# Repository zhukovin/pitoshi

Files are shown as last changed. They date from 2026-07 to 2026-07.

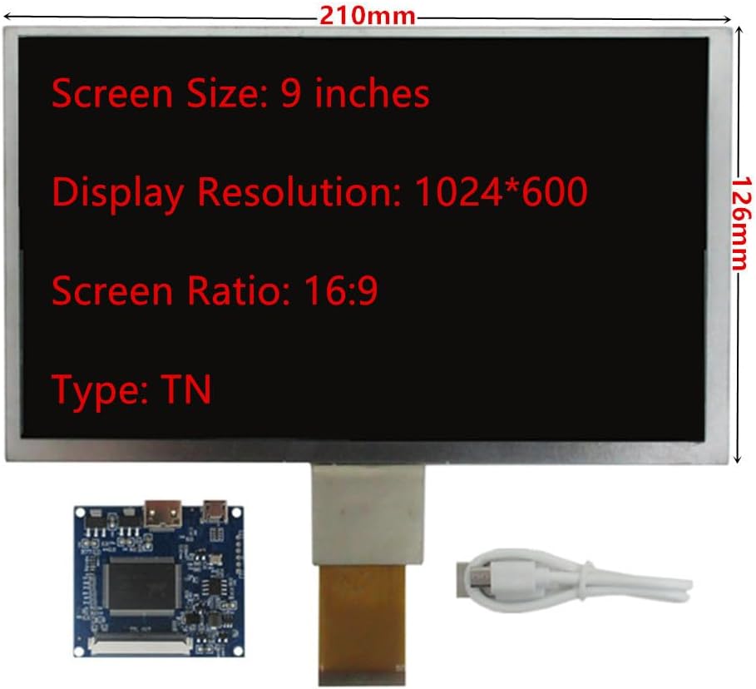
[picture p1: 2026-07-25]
display/docs/51enpO84WiL._AC_SL1000_.jpg

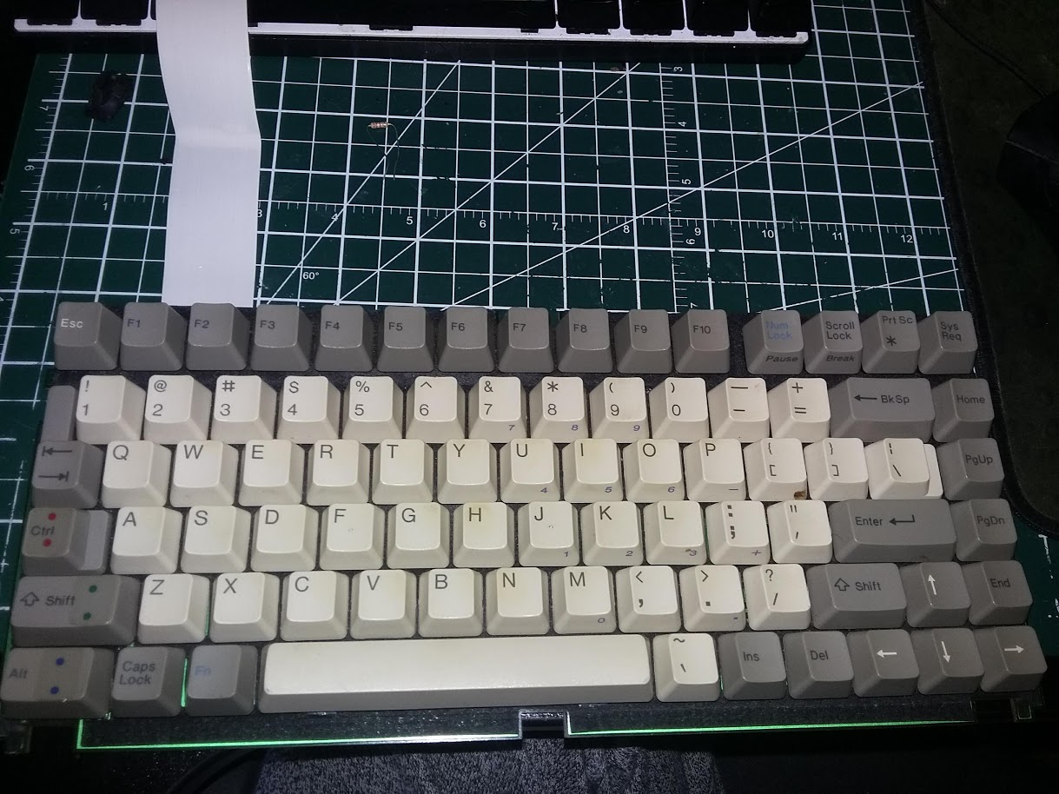
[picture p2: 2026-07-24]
keyboard/docs/misc/xawLbd5.jpeg

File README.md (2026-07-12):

# Toshiba T1200XE Keyboard USB Controller using Raspberry Pi Pico + KMK

## Overview

This project converts the original Toshiba T1200XE laptop keyboard into a modern USB keyboard using a Raspberry Pi Pico (RP2040).

Unlike many modern keyboards, the Toshiba keyboard:

- is a raw keyboard matrix
- has a diode on every key
- uses **active HIGH scanning**
- requires rows to be driven HIGH and columns to use PULL_DOWN inputs

This document describes everything required to reproduce the project from scratch.

---

# Hardware

- Raspberry Pi Pico (RP2040)
- Toshiba T1200XE keyboard
- USB cable
- Soldered connections between keyboard ribbon and Pico GPIO

---

# Software Required

1. CircuitPython
2. CircuitPython Library Bundle
3. adafruit_hid
4. KMK Firmware

---

# IDE Setup (IntelliJ IDEA)

IDEA does not ship with CircuitPython stubs, so `import board`, `import busio`, etc. will show as unresolved by default. Fix:

1. Create a virtual environment in the project root:

```bash
python3 -m venv .venv
source .venv/bin/activate
pip install circuitpython-stubs
```

2. Point IDEA to the venv interpreter:
   `File → Project Structure → Project Settings → Project → SDK → open dropdown → Add Python SDK from disk… → Select existing → Python path → select .venv/bin/python`

3. Invalidate caches to force IDEA to index the new stubs:
   `File → Invalidate Caches → Invalidate and Restart`

After restart, `board`, `busio`, `digitalio`, and other CircuitPython modules will resolve correctly.

> Do not install the PyPI package named `board` — it is unrelated to CircuitPython and will not help.

---

# Installing CircuitPython

Download the latest firmware:

https://circuitpython.org/board/raspberry_pi_pico/

Install:

1. Hold BOOTSEL.
2. Connect Pico to USB.
3. Pico appears as

```
RPI-RP2
```

4. Drag the downloaded `.uf2` file onto the drive.

After reboot it appears as

```
CIRCUITPY
```

---

# Connecting to the Serial Console

The Pico exposes a USB serial (CDC) device once CircuitPython is installed. This is how you see `print()` output, KMK debug logs, and the REPL.

## 1. List available tty devices

**macOS:**

```bash
ls /dev/tty.*
```

The Pico shows up as something like `/dev/tty.usbmodem14101`.

**Linux (including Raspberry Pi):**

```bash
ls /dev/ttyACM*
```

The Pico is usually `/dev/ttyACM0` (or the next free number if other USB-serial devices are already connected).

If several devices are listed and you're not sure which one is the Pico, unplug it, re-run the `ls` command, plug it back in, and re-run again — the device that appears is the Pico. On Linux you can also confirm with:

```bash
ls -la /dev/serial/by-id/
```

which prints a descriptive name (e.g. containing `Raspberry_Pi_Pico` or `CircuitPython`) instead of a generic device number.

## 2. Open the serial console with `screen`

```bash
screen /dev/tty.usbmodem14101 115200
```

(substitute the actual device path from step 1; the baud rate `115200` is conventional and CircuitPython ignores it over USB, but you still need to supply a value).

You should land on a blank terminal connected to the board. If `code.py` is running, any `print()` output or KMK debug lines will stream in as they happen. Press Enter if you see nothing — sometimes the first line is swallowed by `screen` attaching mid-output.

## 3. Useful keys once connected

- **Ctrl+D** — soft-reboot: reloads and re-runs `code.py`.
- **Ctrl+C** — interrupt the running program and drop into the REPL.
- **Ctrl+A** then **K**, then **y** — kill the `screen` session (disconnects so another program, like Mu, can open the port).
- **Ctrl+A** then **D** — detach without killing the session (reattach later with `screen -r`).

Only one program can hold the serial port open at a time — if `screen` won't connect, make sure Mu, `tio`, Arduino IDE's serial monitor, etc. aren't already attached to the same device.

---

# Verify CircuitPython

Create `code.py`

```python
print("Hello CircuitPython")
```

Press Ctrl+D in the serial console.

Expected:

```
Hello CircuitPython
```

---

# Install CircuitPython Libraries

Download:

https://circuitpython.org/libraries

Choose the bundle matching your CircuitPython version.

Extract it.

---

# Install adafruit_hid

Copy

```
lib/adafruit_hid
```

from the bundle into

```
CIRCUITPY/lib/
```

Verify:

```python
from adafruit_hid.keyboard import Keyboard
from adafruit_hid.keycode import Keycode

print("HID installed")
```

---

# Test USB HID

```python
import usb_hid
from adafruit_hid.keyboard import Keyboard
from adafruit_hid.keycode import Keycode

kbd = Keyboard(usb_hid.devices)

kbd.press(Keycode.A)
kbd.release_all()
```

Opening a text editor should automatically type

```
a
```

---

# Install KMK

Download:

https://github.com/KMKfw/kmk_firmware

Copy the folder

```
kmk
```

to

```
CIRCUITPY/
```

Final structure:

```
CIRCUITPY/
│
├── code.py
├── kmk/
└── lib/
    └── adafruit_hid/
```

Verify:

```python
from kmk.keys import KC

print("KMK installed")
```

---

# Toshiba Keyboard Matrix

The Toshiba T1200XE keyboard is

```
8 rows
11 columns
```

Total GPIO required:

```
19
```

---

# GPIO Assignment

Rows

```python
ROWS = [
    board.GP11,
    board.GP12,
    board.GP13,
    board.GP14,
    board.GP20,
    board.GP15,
    board.GP22,
    board.GP21,
]
```

Columns

```python
COLS = [
    board.GP0,
    board.GP1,
    board.GP2,
    board.GP4,
    board.GP3,
    board.GP6,
    board.GP5,
    board.GP7,
    board.GP8,
    board.GP9,
    board.GP10,
]
```

---

# Matrix Polarity

Initially the keyboard was assumed to use the common polarity:

```
Rows LOW
Columns PULL_UP
```

Nothing worked.

Testing revealed that Toshiba uses the opposite polarity.

Correct scan:

```
Rows OUTPUT

inactive = LOW
active = HIGH

Columns INPUT

PULL_DOWN

Pressed key = HIGH
```

This was verified experimentally.

---

# Matrix Scanner

The discovery scanner works like:

```
For every row

    set every row LOW

    drive current row HIGH

    read every column

    if HIGH

        key pressed
```

This scanner was used to build the entire keyboard matrix.

---

# Key Matrix

(The completed matrix mapping goes here.)

Example:

| Row  | Col  | Key  |
|---|---|---|
| 0 | 0 | F1 |
| 0 | 1 | F2 |
| 0 | 2 | Esc  |
| ...  | ...  | ...  |

---

# KMK Configuration

Example:

```python
import board

from kmk.kmk_keyboard import KMKKeyboard
from kmk.keys import KC
from kmk.scanners import DiodeOrientation

keyboard = KMKKeyboard()

keyboard.row_pins = (
    board.GP11,
    board.GP12,
    board.GP13,
    board.GP14,
    board.GP20,
    board.GP15,
    board.GP22,
    board.GP21,
)

keyboard.col_pins = (
    board.GP0,
    board.GP1,
    board.GP2,
    board.GP4,
    board.GP3,
    board.GP6,
    board.GP5,
    board.GP7,
    board.GP8,
    board.GP9,
    board.GP10,
)

keyboard.diode_orientation = DiodeOrientation.ROW2COL
```

---

# Debounce

Initially

- Enter occasionally generated two presses.
- Shift sometimes failed.

Adding debounce solved the problem.

Example:

```python
from kmk.modules.debounce import Debounce

keyboard.modules.append(Debounce())
```

---

# Disable KMK Debug

If KMK prints

```
kmk.keyboard:
```

messages continuously

disable debugging:

```python
import kmk

kmk.debug_enabled = False
```

---

# Disable CircuitPython REPL

Create `boot.py`

```python
import usb_cdc

usb_cdc.enable(console=False, data=True)
```

This removes the REPL console while keeping a serial data port.

---

# Disable USB MIDI (Pico Shows Up as a Sound Card)

CircuitPython enables a USB MIDI interface by default. USB MIDI streaming
is technically a subclass of the USB *Audio* class, so on Linux hosts it
shows up as an extra ALSA sound card (`cat /proc/asound/cards` lists it as
`Pico [USB-Audio]`) even though KMK never uses it and no real audio is
involved. Harmless, but confusing when diagnosing audio setups.

Create `boot.py`

```python
import usb_midi

usb_midi.disable()
```

`boot.py` only runs on a full boot, not on the auto-reload triggered by
saving `code.py` — unplug and replug the Pico (or press its reset button)
for this to take effect.

---

# Testing

Test in this order:

- letters
- numbers
- arrows
- Shift
- Ctrl
- Alt
- Enter
- Backspace

---

# Future Improvements

## Fn Key

Implement Toshiba Fn layer using KMK Layers module.

Possible functions:

- brightness
- volume
- overlay keypad
- function remapping

---

## Media Keys

KMK supports:

- Volume Up
- Volume Down
- Mute
- Play
- Pause

---

## Multiple Layers

Possible layers:

Layer 0

Original Toshiba layout

Layer 1

Fn layer

Layer 2

Gaming

Layer 3

Mac layout

---

# Lessons Learned

The most important discovery during reverse engineering was that the Toshiba keyboard **does not use the common active-low scan method**.

Correct operation requires:

```
Rows:
    OUTPUT
    inactive LOW
    active HIGH

Columns:
    INPUT
    PULL_DOWN

Pressed key:
    HIGH
```

This single discovery made the keyboard immediately functional.

---

# Useful Links

CircuitPython

https://circuitpython.org/

CircuitPython Libraries

https://circuitpython.org/libraries

KMK

https://github.com/KMKfw/kmk_firmware

KMK Documentation

https://kmkfw.io

Raspberry Pi Pico

https://www.raspberrypi.com/products/raspberry-pi-pico/

---

Project status:

✅ CircuitPython installed

✅ USB HID working

✅ Keyboard matrix reverse engineered

✅ Active-HIGH polarity discovered

✅ GPIO mapping complete

✅ Key matrix mapped

✅ KMK running

✅ Toshiba keyboard fully functional over USB

## Manually Creating a Wi-Fi Connection with NetworkManager

If the Raspberry Pi detects nearby Wi-Fi networks (`iwlist wlan0 scan` works) but does not have any saved Wi-Fi connections (`nmcli connection show` only lists `lo` and `Wired connection 1`), you can manually create a connection profile.

### 1. Create a new Wi-Fi connection

```bash
sudo nmcli connection add \
    type wifi \
    ifname wlan0 \
    con-name home \
    ssid "az"
```

This creates a new connection profile named **home** for the Wi-Fi network with SSID **az**.

### 2. Configure the security type

```bash
sudo nmcli connection modify home \
    wifi-sec.key-mgmt wpa-psk
```

This tells NetworkManager that the network uses WPA/WPA2 Personal authentication.

### 3. Set the Wi-Fi password

```bash
sudo nmcli connection modify home \
    wifi-sec.psk "12345678"
```

### 4. Activate the connection

```bash
sudo nmcli connection up home
```

If successful, the Raspberry Pi will obtain an IP address from the router.

### 5. Verify the connection

Check the assigned IP address:

```bash
ip addr show wlan0
```

Test Internet connectivity:

```bash
ping -c 4 8.8.8.8
```

Test DNS resolution:

```bash
ping -c 4 google.com
```

### Useful NetworkManager commands

List all saved connections:

```bash
nmcli connection show
```

List network devices:

```bash
nmcli device
```

Show detailed information about the Wi-Fi interface:

```bash
nmcli device show wlan0
```

List nearby Wi-Fi networks:

```bash
nmcli device wifi list
```

Force a Wi-Fi rescan:

```bash
nmcli device wifi rescan
```

Bring the connection up again later:

```bash
sudo nmcli connection up home
```

Disconnect from Wi-Fi:

```bash
sudo nmcli connection down home
```

Delete the connection profile:

```bash
sudo nmcli connection delete home
```

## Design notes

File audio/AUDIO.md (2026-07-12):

# Audio Setup — PAM8406 Amp via the 3.5mm Jack

Hardware: Raspberry Pi 3 Model B (Rev 1.2), a PAM8406 class-D amp board, two
speakers, connected through the Pi's built-in 3.5mm AV jack. Display is
HDMI-only (no speakers), so the analog jack is the only audio output that
matters here.

## TL;DR — The Fix

The Pi has **two separate ALSA sound cards** and it's easy to test the wrong
one:

```
card 0: vc4hdmi     [vc4-hdmi]           — HDMI audio (no speakers on this display)
card 1: Headphones  [bcm2835 Headphones] — the analog 3.5mm jack you actually want
card 2: Pico        [USB-Audio]          — the keyboard project's own Pico, enumerates as a sound card
```

Find your own card numbers (they can differ by OS image/revision):

```
aplay -l
cat /proc/asound/cards
```

Test the *analog* card directly, bypassing PipeWire, to confirm the hardware
path works at all:

```
speaker-test -D plughw:1,0 -c2 -twav -l1
```

Make sure PipeWire's default output sink is the analog device, not HDMI:

```
wpctl status                 # look under Audio → Sinks for the "*" (default) marker
wpctl set-default <id>       # id of "Built-in Audio Stereo" (NOT the one labeled "(HDMI)")
wpctl set-mute <id> 0
wpctl set-volume <id> 100%
```

Confirm PipeWire itself can play sound through it:

```
pw-play /usr/share/sounds/alsa/Front_Center.wav
```

**Persist across reboot** — two layers need saving, PipeWire's default-sink
preference and the raw ALSA hardware mixer level:

```
wpctl set-default <id>              # WirePlumber remembers this by device name, survives reboot
amixer -c 1 sset PCM 100% unmute    # raw hardware gain — resets on reboot unless saved
sudo alsactl store 1                # writes card 1's mixer state to /var/lib/alsa/asound.state,
                                     # reloaded automatically at boot by the alsa-restore service
```

Verify with a reboot:

```
sudo reboot
# after it comes back:
wpctl status
speaker-test -D plughw:1,0 -c2 -twav -l1
```

`wpctl status` will show a new numeric sink id (ids are reassigned every
boot) but the same device should still be marked default `*`, and
`Settings → Default Configured Devices` should list something like
`alsa_output.platform-3f00b840.mailbox.stereo-fallback` — that's the
persisted preference, keyed by device name rather than the id.

### Two things that look like bugs but aren't

- **50Hz hum when you touch the bare jack, before anything is really
  playing.** Normal. A high-impedance analog audio line picks up ambient
  mains hum capacitively through your body when touched. It doesn't indicate
  a fault. If the hum persists *during actual playback*, that's a different
  problem — almost always a ground loop between the Pi's power supply and
  the amp's power supply if they're on separate wall adapters. Fix by
  sharing a common ground (power the PAM8406 from the Pi's own 5V rail, or
  put both PSUs on the same power strip) or adding an inline ground-loop
  isolator.
- **`amixer` reports `Playback channels: Mono` for card 1's `PCM` control.**
  That's describing the *mixer control*, not the audio stream. Capabilities
  `pvolume-joined pswitch-joined` mean the Pi's onboard PWM-based DAC only
  exposes one shared volume/mute register for both channels — there's no
  independent L/R gain in hardware. The actual PCM path is genuine 2-channel
  stereo, confirmed by `speaker-test -c2` announcing distinct "Front Left" /
  "Front Right" and both speakers working independently through the
  PAM8406.
- **Card 2, `Pico [USB-Audio]`, isn't a real audio device either.** It's
  the keyboard project's own Raspberry Pi Pico. CircuitPython enables a USB
  MIDI interface by default, and USB MIDI streaming is technically a
  subclass of the USB *Audio* class, so Linux's `snd-usb-audio` driver
  picks it up as a sound card even though no real audio is involved. It's
  not the cause of any audio bug here, but it's worth silencing so it can't
  confuse future diagnostics (or ever become a stray default sink via
  WirePlumber's hotplug auto-switching, see step 7). Create `boot.py`
  alongside `code.py` on the `CIRCUITPY` drive:

  ```python
  import usb_midi

  usb_midi.disable()
  ```

  `boot.py` only runs on a full boot, not on the auto-reload triggered by
  saving `code.py` — unplug and replug the Pico (or press its reset button)
  for this to take effect. See the main `README.md`'s "Disable USB MIDI"
  section.

---

## Diagnostic Journey — How We Got Here

### 1. The symptom

No sound at all through the PAM8406 + speakers when connected via the
3.5mm jack. Touching the bare jack produced a 50Hz hiss on both channels.
Working theory going in: the Pi is routing audio to HDMI, and the HDMI
display has no speakers to reveal that.

### 2. Identify the audio stack

```
pactl --version 2>/dev/null && echo "PulseAudio"
wpctl status 2>/dev/null && echo "PipeWire"
```

Result: PipeWire 1.4.2 (Raspberry Pi OS Bookworm default), not PulseAudio.
This determined which command family to use for the rest of the
investigation (`wpctl`/`pw-*` instead of `pactl`).

### 3. First look at `wpctl status`

```
wpctl status
```

Showed two sinks:

```
35. Built-in Audio Digital Stereo (HDMI) [vol: 0.40]
58. Built-in Audio Stereo               [vol: 1.00]   ← marked default (*)
```

This complicated the initial "it's routed to HDMI" theory — PipeWire
already believed the analog sink was default, at full volume, unmuted.
Something below the PipeWire layer had to be the culprit.

### 4. Rule out a muted/zero PipeWire sink and a jack-less Pi 5

```
wpctl get-volume 58        # → Volume: 1.00, not [MUTED]
cat /proc/device-tree/model # → Raspberry Pi 3 Model B Rev 1.2
```

The volume readout confirmed the sink wasn't secretly muted at the
PipeWire layer. The model check ruled out a real gotcha: the Raspberry Pi 5
removed the analog 3.5mm audio jack entirely, so a "healthy-looking" ALSA
node can exist in software with no physical jack behind it. Not the case
here — a Pi 3B genuinely has the jack.

### 5. Drop to the raw ALSA mixer

```
amixer -c 0 controls
```

```
numid=1,iface=CARD,name='HDMI Jack'
numid=6,iface=MIXER,name='PCM Playback Volume'
numid=5,iface=PCM,name='ELD'
numid=4,iface=PCM,name='IEC958 Playback Default'
numid=3,iface=PCM,name='IEC958 Playback Mask'
numid=2,iface=PCM,name='Playback Channel Map'
```

The controls on card 0 are all HDMI-specific (`HDMI Jack`, `ELD`,
`IEC958`/S/PDIF). **Card 0 is the HDMI audio card, not the analog jack.**
Any test run against `hw:0` or `plughw:0,0` was silently testing the wrong
device the entire time.

### 6. Confirm the wrong-card theory

```
speaker-test -D plughw:0,0 -c2 -twav -l1
```

Silent, as expected — this was playing to the HDMI card, and the monitor
has no speakers.

### 7. Enumerate the real cards

```
aplay -l
cat /proc/asound/cards
```

```
card 0: vc4hdmi        - vc4-hdmi
card 1: Headphones     - bcm2835 Headphones     ← the real analog jack
card 2: Pico           - USB-Audio, Raspberry Pi Pico
```

Card 1 is the actual analog output. Card 2 was an unexpected find: the
Toshiba keyboard's own Pico microcontroller enumerates as a USB audio
device on this machine, purely incidental to this repo's KMK firmware
project. Not the cause of the silence, but flagged as a future gotcha —
WirePlumber tends to auto-switch its default sink to the most recently
connected audio device, so unplugging/replugging the keyboard could
someday flip default output away from the speakers.

### 8. Test the correct card

```
speaker-test -D plughw:1,0 -c2 -twav -l1   # ALSA-direct, bypassing PipeWire — worked
pw-play /usr/share/sounds/alsa/Front_Center.wav  # through PipeWire's existing default sink — also worked
```

Both worked. Conclusion: there never was a real routing bug — PipeWire had
the correct analog sink set as default from the start. Every earlier
"no sound" result was from pointing test commands (`plughw:0,0`) at the
HDMI card by mistake.

### 9. Make it durable

Since the working state was arrived at manually mid-session, the last step
was ensuring it survives a reboot rather than reverting to whatever
PipeWire/ALSA pick by default:

```
wpctl set-default 58
wpctl set-mute 58 0
wpctl set-volume 58 100%
amixer -c 1 sset PCM 100% unmute
sudo alsactl store 1
sudo reboot
```

### 10. Verify persistence

Post-reboot:

```
wpctl status
```

```
45. Built-in Audio Digital Stereo (HDMI) [vol: 0.40]
55. Built-in Audio Stereo               [vol: 1.00]   ← still marked default (*)
...
Settings
 └─ Default Configured Devices:
         0. Audio/Sink alsa_output.platform-3f00b840.mailbox.stereo-fallback
```

The sink's numeric id changed (58 → 55, ids are reassigned every boot) but
it's still the default, at full volume, and the `Default Configured
Devices` entry shows WirePlumber persisted the choice by device name —
exactly what `wpctl set-default` is supposed to produce.

### 11. One last loose end: "why does it say Mono?"

```
amixer -c 1 sset PCM 100% unmute
```

```
Simple mixer control 'PCM',0
  Capabilities: pvolume pvolume-joined pswitch-joined
  Playback channels: Mono
  Limits: Playback -10239 - 400
  Mono: Playback 400 [100%] [4.00dB] [on]
```

`pvolume-joined pswitch-joined` means the volume and mute switch are a
single control shared by both channels — the Pi's onboard PWM-based analog
DAC just doesn't expose independent per-channel gain in hardware. That's
why the *simple mixer control* is labeled "Mono." The PCM audio stream
itself is real 2-channel stereo, as already proven in step 8 by
`speaker-test -c2` announcing distinct Front Left / Front Right channels
and both speakers working correctly off the PAM8406.

### 12. Silencing the phantom sound card

Card 2 (`Pico [USB-Audio]`, spotted in step 7) turned out to be the
keyboard's own microcontroller, not anything audio-related — CircuitPython
enables a USB MIDI interface by default, and MIDI streaming is a subclass
of the USB Audio class, so `snd-usb-audio` claims it. It never caused this
particular bug, but left alone it's a standing risk for WirePlumber to
someday auto-switch default output to it on hotplug. Fixed at the source,
in the keyboard firmware repo, with `boot.py`:

```python
import usb_midi

usb_midi.disable()
```

After unplugging/replugging the Pico, `cat /proc/asound/cards` no longer
lists it.

## Cast of Commands

| Command | What it told us |
|---|---|
| `pactl --version` / `wpctl status` | Which audio server is running (PipeWire, not Pulse) |
| `wpctl status` | Sink list, which one is default, software volume |
| `wpctl get-volume <id>` | Whether a sink is muted at the PipeWire layer |
| `cat /proc/device-tree/model` | Confirms the board actually has a physical 3.5mm jack (Pi 5 doesn't) |
| `amixer -c <N> controls` / `scontrols` | Raw ALSA mixer controls for a card — reveals what the card actually *is* (HDMI vs analog) |
| `aplay -l` / `cat /proc/asound/cards` | Ground-truth list of ALSA card indices and names |
| `speaker-test -D plughw:<N>,0 -c2 -twav -l1` | ALSA-direct playback test, bypassing PipeWire entirely |
| `pw-play <file>` | Playback test through PipeWire's current default sink |
| `wpctl set-default <id>` / `set-mute` / `set-volume` | Pin PipeWire's default sink, persisted by device name |
| `amixer -c <N> sset PCM 100% unmute` + `sudo alsactl store <N>` | Save the raw ALSA hardware mixer level so it survives reboot |
| `boot.py` with `usb_midi.disable()` (on the Pico) | Stops the keyboard's Pico from enumerating as a phantom `USB-Audio` sound card |

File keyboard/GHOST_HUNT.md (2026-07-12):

# The Ghost Hunt

### How a 1987 Toshiba keyboard, a Raspberry Pi Pico, and a service manual PDF conspired to teach me more about connector corrosion than I ever wanted to know.

---

## Prologue

This repo exists because a Toshiba T1200XE keyboard — the real deal, raw matrix, active-high rows, diode on every key — got a second life behind a Raspberry Pi Pico running [KMK](https://github.com/KMKfw/kmk_firmware). CircuitPython installed, matrix reverse-engineered, polarity quirks discovered the hard way (see the README's "Lessons Learned" — rows HIGH, columns pulled down, opposite of what every tutorial assumes). By the time the Fn layer and NumLock overlay were working, it felt done.

It was not done.

## Chapter 1 — Six Keys That Wouldn't Behave

The symptom showed up as double-vision on the function-key strip. Run `xev`, press a key, watch what comes out:

```
F3        -> F3, Next (PgDn)
F5        -> F5, F7
F7        -> F7, F9
F8        -> F8, F10
F9        -> F9, End
Next(PgDn)-> Next, F5
```

Six keys, all misbehaving, all producing exactly *one* extra keystroke each. And, separately, a seventh mystery: PrtSc produced nothing at all — not even a hint of activity.

The obvious question, and the one this whole hunt was really about: **is this hardware or software?** A 39-year-old keyboard and a freshly-written matrix scanner are both perfectly capable of being the culprit, and nothing about "I press one key, two happen" tells you which.

## Chapter 2 — Teaching the Firmware to Confess

The keymap looked clean — every matrix position mapped to exactly one key, no obvious dual-binding bug. But "the code looks right" isn't evidence. What was needed was a window into what the *matrix scanner itself* was seeing, before KMK's key-processing had a chance to touch it.

KMK already had the hook for this — one flag flip:

```python
Debug(__name__).enabled = True
```

...and a serial console (`screen /dev/tty.usbmodemXXXX 115200`) turned the Pico into a live logger of every raw scan event. Press F3, and instead of guessing, you'd *see* this:

```
395179 kmk.keyboard: <Event: key_number 22 pressed>: KeyboardKey(code=60)
395221 kmk.keyboard: <Event: key_number 33 pressed>: KeyboardKey(code=78)
395297 kmk.keyboard: <Event: key_number 22 released>: KeyboardKey(code=60)
395308 kmk.keyboard: <Event: key_number 33 released>: KeyboardKey(code=78)
```

Two genuinely distinct matrix positions (`22` and `33`) firing from one physical keypress. Case closed on "is this a firmware keymap bug" — it flatly wasn't. The ghost was happening at the electrical level, before software ever got a vote. **Hardware, confirmed.**

But *what kind* of hardware fault was still wide open.

## Chapter 3 — Finding the Shape of the Problem

With `key_number = row × 11 + col` in hand, the six broken pairs turned into coordinates, and the coordinates turned into a pattern: every ghost was the **same column, the next row in scan order** — a chain running row 2 through row 7. Rows 0 and 1 (F1/F2, F11/F12) sat outside it entirely.

That looked like a smoking gun for a scanning-timing artifact — until a control test broke the theory cleanly. TAB lives at row 2, column 2, right next to F3's row 2, column 0. If the *row* itself were compromised, TAB should ghost into Q below it exactly like F3 ghosts into PgDn.

TAB was rock solid. Every single time.

So the fault wasn't "row 2's wire is bad" — it was specific to *columns 0 and 1*, the narrow two-column strip where all the F-keys live. Theory revised: something localized to that F-key strip, not the row conductors generally.

Then a second axis showed up, unannounced. Pressing F12 occasionally produced F12 *and* F11 — a same-row, neighboring-*column* ghost, the mirror image of the row-axis chain:

```
!! GHOST: F12 press also saw F11, ~40ms later, intermittent (~29% of presses)
```

And then F4 → F3, which turned out to be the most reliable ghost of the entire investigation — **100% reproducible**, a tight and consistent ~15ms lag every single time, versus the 12-70ms jittery lag everywhere else. Not all ghosts were equal; some pairs had a much more "established" fault than others.

By now there were two independent axes of crosstalk (row-adjacent *and* column-adjacent), variable intermittency per pair, and a working hypothesis: **general degradation across the whole F-key strip**, not one single crack in one single spot.

## Chapter 4 — Ruling Out the Diode

A keyboard where "every key has a diode" invites an obvious question: is a bad diode doing this? The answer turned out to be no, and *why not* is worth remembering: a per-key diode sits in series with its own switch. A shorted F3 diode wouldn't make col0 spike only when F4 is pressed — it would make F3 fire on *every single scan* of its row, constantly, since diode current doesn't care whether F4 is pressed at all. That's not what was happening. The real requirement was a path that bypassed the switches and diodes entirely — a bridge directly between two column (or row) *traces*.

And the fact that the ghosting only ever ran one direction (F4→F3, never F3→F4) pointed at something specific: not a clean resistive short, but something with a built-in asymmetry — corrosion between two copper surfaces can behave like an accidental rectifying junction (the "rusty bolt effect"), conducting one way far better than the other. Nobody needed to open the keyboard to guess this; it was a prediction the evidence made *before* the connector was ever inspected.

## Chapter 5 — Building Instruments

Eyeballing debug logs one keypress at a time doesn't scale to "let's get a statistically convincing number of samples." So the toolbox grew:

- **`diagnostics/ghost_key_test.py`** — talks straight to `keypad.KeyMatrix`, bypassing KMK and the OS entirely. Walks a target key, counts clean presses, and the instant a ghost shows up mid-press it prints exactly what leaked in and moves on. First real-world run: pointed at F7, ghost caught on **press #1**.
- **`diagnostics/pattern_anomaly_test.py`** — the free-form version. No fixed target, no script to follow — just mash the keyboard naturally, and it watches for any key showing up while another is still held (which should never happen if you're only pressing one key at a time). Catches anomalies anywhere on the board, not just the already-known F-key suspects, and prints them as a compact pattern:

  ```
  !! I saw this pattern "aaabaaa" - is that intended?
     a=F7, b=F9
  ```

  with a live single-line counter (`F7 x7`) that keeps ticking through the noise, only breaking to a new line when you genuinely switch keys.

The full-strip walk of `ghost_key_test.py` actually produced a false-negative-*looking* result once — F7 tested clean after a 500-press slog through F1 through F6 first. Not a bug: it just never got a fair shot at F7 before patience ran out. Lesson learned and folded back into the tool: an `ONLY_TEST = ['F7']` override to jump straight to the key in question, which is exactly what caught the ghost on the very next attempt.

## Chapter 6 — The PCB, the Tape, and an Alibi

A scan of the keyboard PCB's solder side came next — dense fields of solder joints, scattered black axial diodes, and a Sumitomo FFC ribbon exiting toward what used to be the system board. Two blue tape flags marked, by hand, the physical locations the multimeter should care about: F7 and F9.

Zooming into those tape marks (a few rounds of `sips --cropOffset` standing in for a proper macro lens) revealed tiny silkscreened reference numbers: **118** and **120**. And sitting silently *between* them, unmarked: **119** — almost certainly F8.

That was a small, sharp piece of evidence. If the fault were simple physical adjacency — two neighboring pads on the board touching — F8 should be the first casualty, sitting as it does directly between F7 and F9. It wasn't (on that axis, anyway — more on that in a moment). Whatever was bridging row 5 and row 6 wasn't happening at the keyswitch pads at all. It was happening somewhere else entirely.

## Chapter 7 — The Rosetta Stone

The somewhere else turned out to be hiding in plain sight, in a page from Toshiba's own service manual: **Table B-14, Keyboard I/F connector pin assignment**. Eleven `KBOT` column-strobe lines, eight `KBRT` row-return lines, each with its own connector pin number.

Lining that table up against `code.py`'s oddly-jumbled `row_pins` tuple (`GP11, GP12, GP13, GP14, GP20, GP15, GP22, GP21` — which never made much sense as a deliberate GPIO choice) suddenly explained everything: it wasn't random at all. It was simply the connector's pins, 14 through 22, wired in physical order to whatever Pico pin was next in reach. Once that clicked, every single ghost pair could be translated into **connector pin numbers**:

| Ghost pair | Connector pins | Adjacent? |
|---|---|---|
| F3 → PgDn | 16 ↔ 17 | yes |
| F5 → F7 | 19 ↔ 20 | yes |
| **F7 → F9** | **20 ↔ 21** | **yes** |
| F9 → End | 21 ↔ 22 | yes |
| F4 → F3 | 2 ↔ 1 | yes |
| F12 → F11 | 2 ↔ 1 | yes (same pins) |
| PgDn → F5 | 17 ↔ 19 | one pin gap (GND) |

Six of seven ghosts, every single one, mapped onto **physically adjacent pins on the keyboard's own connector**. Not the PCB matrix. Not the keyswitches. The connector itself — most likely corrosion or contamination bridging neighboring contacts on a decades-old ribbon interface. It also closed the loop on F8's alibi from Chapter 6: F8 was never innocent, it just ghosts through *its own* row-mate pin (into F10, right there in the original six symptoms from Chapter 1) rather than through its physical neighbor on the PCB. Once you're looking at the connector instead of the board, F8's behavior stops being a mystery and becomes confirmation.

## Chapter 8 — Chasing a Ghost That Wouldn't Sit Still

Armed with exact pin numbers, a multimeter in diode-test mode should have been able to close this out. It didn't — every reading at rest came back `1.` (open), on every polarity, on every pin pair. That wasn't a dead end, though; it was consistent with everything already known. The ghost was never a hard, permanent short — it fired on roughly 40-100% of presses depending on the pair, with 10-70ms of jitter and inconsistent release ordering. A DMM sampling a couple of times a second was never going to catch something that transient.

That pushed the investigation toward an oscilloscope setup — trigger on the legitimate keypress, watch the *victim* column line (not the actively-driven row line, which a healthy push-pull output would just stomp flat regardless of a marginal leak) for an unexplained pulse riding in on the neighboring row's timeslot. Persistence mode, mash the key a few dozen times, let the rare ~40% events paint themselves onto the screen as a visibly distinct trace. The plan was solid. It never had to be executed.

## Chapter 9 — The Software Band-Aid

While the physical fix was still an open question, there was no reason to keep living with doubled keystrokes. Since every ghost pair was now precisely characterized — which key triggers which, and roughly how long the lag runs — the fix could be pushed into firmware as a stopgap: **`ghost_filter.py`**, a thin wrapper around `MatrixScanner` that watches raw `key_number` events, and if a known ghost key's press shows up within 200ms of its trigger while the trigger is still held, eats both the press and its matching release before KMK's core ever sees them.

```python
GHOST_MAP = {
    22: {33},  # F3 -> PgDn/Next
    33: {44},  # PgDn/Next -> F5
    44: {55},  # F5 -> F7
    55: {66},  # F7 -> F9
    66: {77},  # F9 -> End
    56: {67},  # F8 -> F10
    12: {11},  # F12 -> F11
    23: {22},  # F4 -> F3
}
```

Deliberately a mitigation, not a cure — it masks the symptom at the cost of a small risk (fine here, since none of these pairs are ever used back-to-back on purpose) and does nothing if the underlying fault ever gets worse. But it meant the keyboard was fully usable while the actual hardware investigation kept going in the background.

## Chapter 10 — The Cure

In the end, the fix was almost anticlimactic compared to the investigation: **isopropyl alcohol**, applied to the connector contacts the service-manual table had pointed to, cleaned away whatever film — corrosion, oxidation, decades of dust — had been marginally bridging those neighboring pins. Ghosting: gone.

It's a satisfying ending precisely *because* it matches the theory built chapter by chapter: an intermittent, force-dependent, one-directional, connector-localized fault is exactly what a thin layer of contamination between two adjacent contacts looks like — and exactly what a swab of IPA fixes.

## Epilogue — The One That Got Away

PrtSc never got its resolution, and it's worth recording *why* it was set aside rather than pretending it was solved. The debug log settled the hardware question decisively:

```
721131 kmk.keyboard: <Event: key_number 75 pressed>: KeyboardKey(code=70)
```

Code 70 is the correct, standard HID usage for Print Screen. The switch, the matrix, and KMK all do their job perfectly. Whatever swallows PrtSc before it reaches `xev` lives downstream — almost certainly a desktop environment or screenshot utility holding a global grab on that key, a very ordinary X11 behavior that has nothing to do with a 1987 keyboard at all. Good to know, not worth chasing further.

## Cast of Tools

| Tool | Role |
|---|---|
| `xev` | Where the mystery started — first sighting of doubled keys |
| KMK `Debug` flag + serial console | Turned the firmware into an eyewitness |
| `diagnostics/ghost_key_test.py` | Scripted, repeatable per-key ghost testing |
| `diagnostics/pattern_anomaly_test.py` | Free-form, whole-keyboard anomaly watch |
| Multimeter (continuity + diode-test mode) | Ruled permanent shorts in and out |
| PCB photos + `sips` crops | Read the board's own silkscreen for ground truth |
| Toshiba service manual, Table B-14 | The Rosetta Stone — pin numbers that cracked the whole case |
| `ghost_filter.py` | The stopgap that kept the keyboard usable mid-investigation |
| Isopropyl alcohol | The actual cure |

## Lessons for Fellow Ghost Hunters

1. **Push the observation point as close to the hardware as you can.** `xev` told us *that* something was wrong; KMK's raw `key_number` log told us *where*, at the electrical level, before any software could be blamed or exonerated.
2. **Let control tests kill your theories.** TAB not ghosting is what actually saved this investigation from stalling on a wrong hypothesis about row conductors.
3. **A photo with a ruler (or in this case, a service manual with pin numbers) beats a guess every time.** The connector table did more in one afternoon than every prior physical inspection combined.
4. **Intermittent and directional is a different animal from "shorted."** Timing jitter and one-way conduction are themselves evidence — they pointed at corrosion long before any cleaning happened.
5. **A software mitigation is not admitting defeat.** Shipping `ghost_filter.py` bought a fully usable keyboard while the real fix was still being hunted down — and it's still sitting there, harmless, now that it has nothing left to catch.

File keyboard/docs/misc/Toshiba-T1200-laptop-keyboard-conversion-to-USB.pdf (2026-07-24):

Toshiba T1200 laptop keyboard conversion to USB.

The key matrix (https://imgur.com/a/L19OMkR) was determined by devicemodder2 and described in a Reddit post (https://www.reddit.com/r/olkb/comments/dk514w/using_existing_laptop_keyboard_from_toshiba_t1200/) as an 11*8 matrix with 11 columns and 8 rows as pictured here. (https://imgur.com/a/yo9EHeh)

The Teensy LC circuit board is designed for an Aliexpress 22 pin 1.25mm pitch connector (https://www.aliexpress.com/item/33053230433.html?spm=2114.12010615.8148356.6.631943d6O5EdmI) with thru-hole pins. The board will also work with a Molex connector (https://www.molex.com/pdm_docs/sd/520452245_sd.pdf) (last time buy) and a TE connector (https://www.te.com/commerce/DocumentDelivery/DDEController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) available from Digikey.

The T1200 connector board has the same Teensy I/O to FPC pin translation table as the standard Teensy LC board seen in my Instructable.

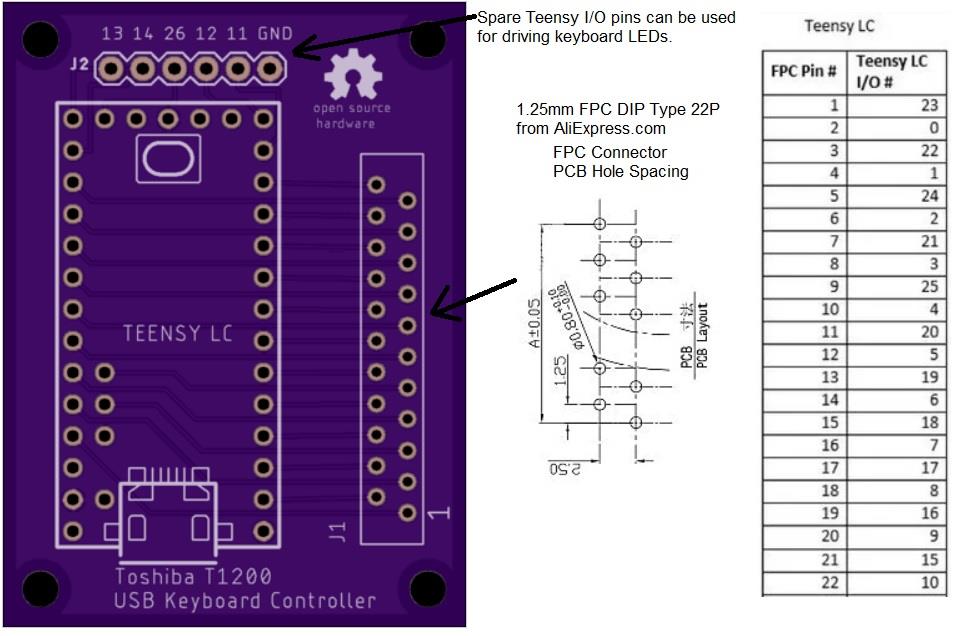
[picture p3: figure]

The Eagle board file “T1200.brd” can be fabricated directly by OSH Park. The zipped Gerber file “T1200_2020-04-27.zip” is formatted for fabrication by JLCPCB.

The schematic file “T1200.sch” is included in this folder in case anyone wants to make changes.

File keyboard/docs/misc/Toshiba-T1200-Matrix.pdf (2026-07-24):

Toshiba T1200 Matrix - FPC Pin numbers are given first, then the Teensy LC I/O-number

Fpc-i/o# | 14-i/o6 | 15-i/o18 | 16-i/o7 | 17-i/o17 | 19-i/o16 | 20-i/o9 | 21-i/o15 | 22-i/o10
1-i/o23 | F1 | Num Lk | F3 | Pg Dn | F5 | F7 | F9 | End
2-i/o0 | F2 | Skrl Lk | F4 | Pg Up | F6 | F8 | F10 | L-Alt
3-i/o22 | Esc | 1 | Tab | Q | A | Cntrl | L-Shift | \
5-i/o24 | 2 | 3 | w | e | s | d | z | x
6-i/o2 | 4 | 5 | r | t | f | g | v | c
7-i/o21 | 6 | 7 | y | u | h | b | n | space
8-i/o3 | 8 | 9 | i | o | j | k | , | m
10-i/o4 | 0 | - | p | L-arrow | L | ; | period | del
11-i/o20 | = | Up arow | [ | ] | Rt-arow | ‘ | / | Caps lk
12-i/o5 | Bk spc | Dn arow | Home | Enter | Tilde | R-shift | Pnt scrn | Insert
13-io19 | Sys-Rqst | Fn

This matrix is from this reddit (https://www.reddit.com/r/olkb/comments/dk514w/using_existing_laptop_keyboard_from_toshiba_t1200/) post. I don’t have the keyboard so I couldn’t test the code (there may be errors). This keyboard has a diode in series with each key switch. I believe the cathodes are connected to the rows and anodes to the columns (but I’m not sure).

Note that connector pins 4, 9, and 18 are grounds.

The Teensy LC USB Keyboard code is “Toshiba_T1200_Keyboard.ino”

Because the Teensy LC is now obsolete, I translated the LC code to work on a Teensy 4.1.

See file name “Toshiba_T1200_Keyboard_4p1.ino”

Use the Easy Soldering board from step 5 of my Instructable (https://www.instructables.com/How-to-Make-a-USB-Laptop-Keyboard-Controller/) with a Teensy 4.1.

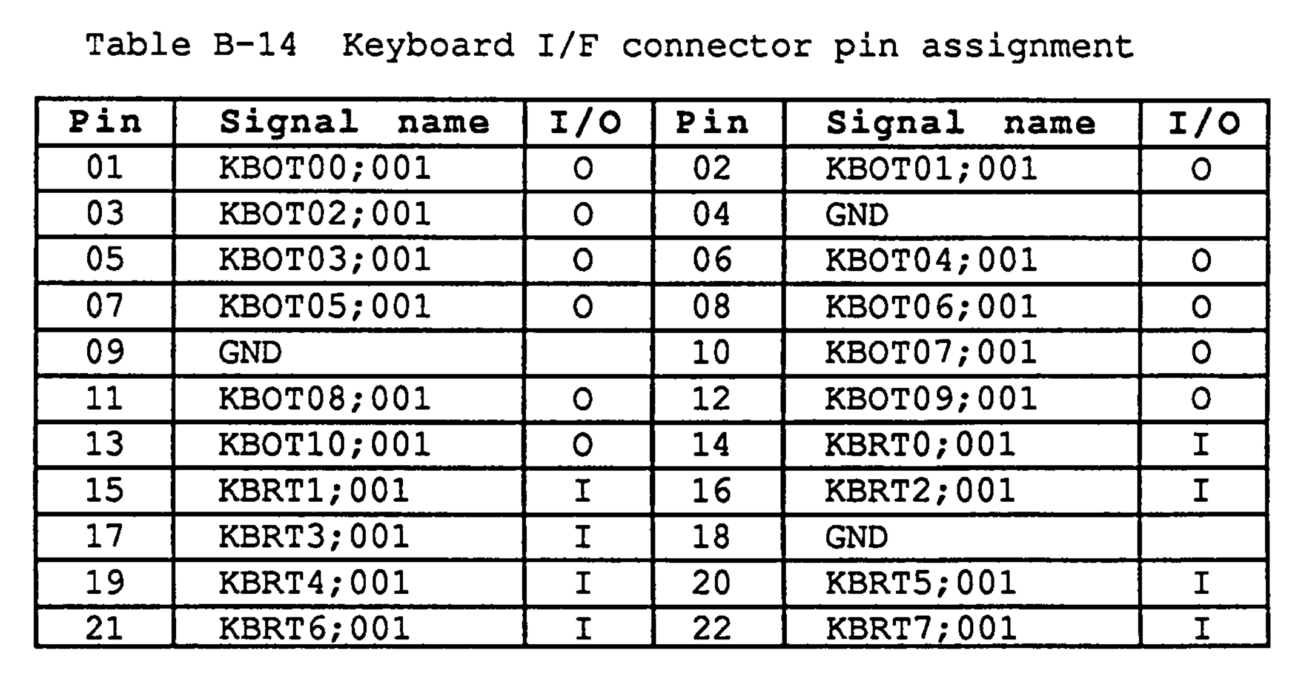
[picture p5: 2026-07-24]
keyboard/docs/keyboard-connector.png

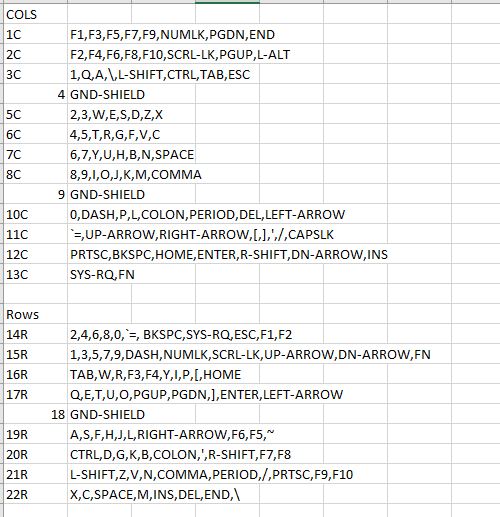
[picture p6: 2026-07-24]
keyboard/docs/misc/matrix.jpeg

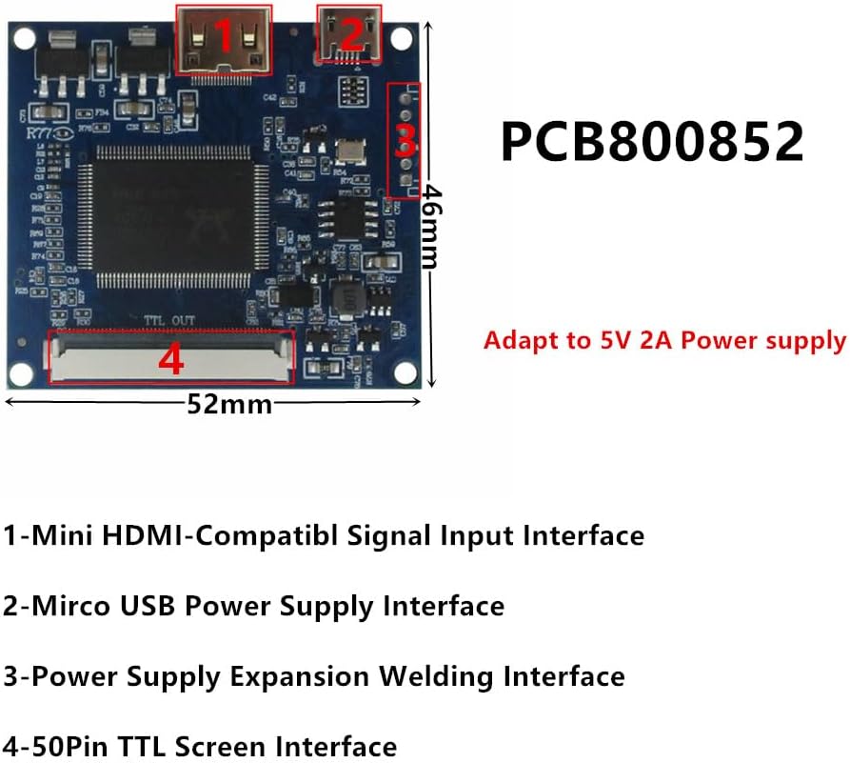
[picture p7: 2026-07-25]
display/docs/61EBnuKXvHL._AC_SL1000_.jpg

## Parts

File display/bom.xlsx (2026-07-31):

Item | URL
Mini HDMI to HDMI Cable 2FT | https://a.co/d/09gNuYRH
Some micro USB for power | ?
9 Inch Mini HDMI Monitor 1024×600 16:9 LCD Display Screen | https://a.co/d/00XWHPks

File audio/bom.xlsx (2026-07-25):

Item | URL
2W 8 Ohm Small Speakers | https://a.co/d/07cjS4fp
PAM8406 Digital Amplifier | https://a.co/d/03uFzbe0
Alternative Items
1W 8 Ohm Mini DIY Magnetic Speaker | https://a.co/d/00tGEICJ

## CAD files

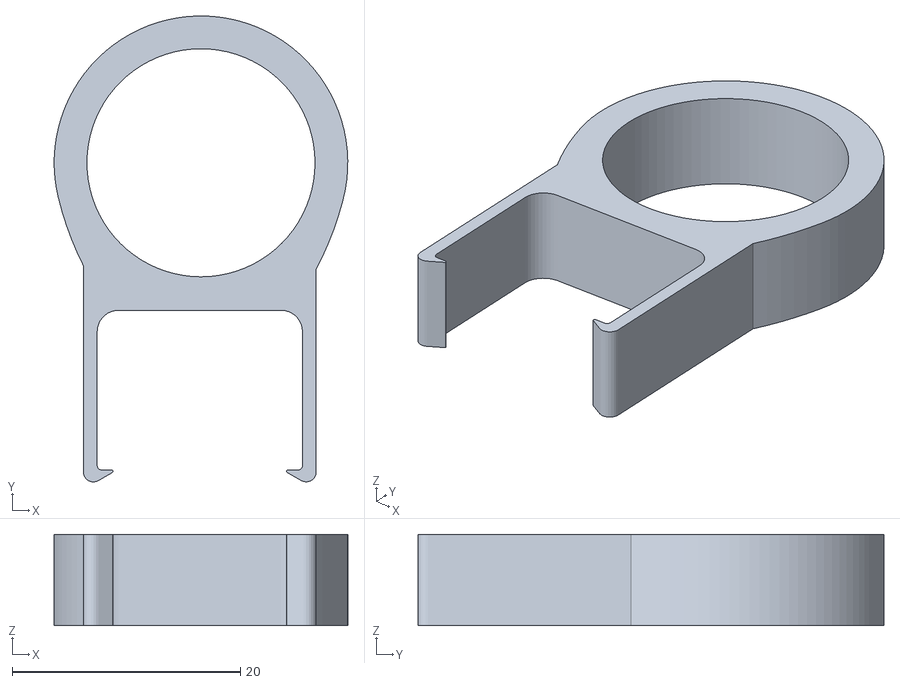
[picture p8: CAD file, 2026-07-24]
keyboard/keycap-puller/keycap-puller-v3.stl
25.7 x 40.9 x 8.00

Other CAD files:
display/toshiba-screen-frame.f3d
keyboard/keycap-puller/keycap-puller-v3.f3d

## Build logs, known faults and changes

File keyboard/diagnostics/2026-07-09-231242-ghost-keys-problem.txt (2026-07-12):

╭─── Claude Code v2.1.201 ─────────────────────────────────────────────────────╮
│                                                    │ Tips for getting        │
│                 Welcome back Alex!                 │ started                 │
│                                                    │ Run /init to create a … │
│                       ▐▛███▜▌                      │ ─────────────────────── │
│                      ▝▜█████▛▘                     │ What's new              │
│                        ▘▘ ▝▝                       │ Claude Sonnet 5 sessio… │
│    Sonnet 5 · Claude Pro · zhukovin@gmail.com's    │ Changed `AskUserQuesti… │
│    Organization                                    │ Changed the "default" … │
│           ~/code/toshiba-t1200xe-keyboard          │ /release-notes for more │
╰──────────────────────────────────────────────────────────────────────────────╯

 ▎ Extended: Fable 5 is included in your weekly limit
 ▎ Through July 12, you can use up to 50% of your weekly usage limit on Fable 5. If you hit your limit, you can continue on Fable 5 with usage credits. Fable 5 draws down usage faster than Opus 4.8. Run /model and select Fable to use it. Learn more
   +1 more · /status

❯ Here is the problem that I am facing with this keyboard. When I press some    
  keys, they produce 2 keys (the rest work just fine). Here are the broken      
  keys:                                                                         
  F3 -> F3, Next (PgDn)                                                         
  F5 -> F5, F7                                                                  
  F7 -> F7, F9                                                                  
  F8 -> F8, F10                                                                 
  F9 -> F9,END                                                                  
  Next (PgDn) -> Next, F5                                                       
                                                                                
  I used rpi's utility xev to monitor keyboard events, so the key names might   
  be unusual (like Next, which means PgDn)                                      
                                                                                
  The other problem is that PrtSc key does not produce any linux event.         
                                                                                
  Please help me debug this, I want to check whether it is a hardware or        
  software problem.                                                             

  Searched for 3 patterns, read 4 files (ctrl+o to expand)

⏺ I found the project — this is a KMK/CircuitPython firmware for a Raspberry Pi
  Pico that scans the original Toshiba keyboard matrix (code.py:34-40, row/col
  pins at code.py:17-26). Mapping your reported keys against the matrix in
  code.py:49-59 reveals a clean pattern.

  The ghosting pattern

  Every broken key maps to (row, col0-or-1), and the "extra" key is always the
  next row in the row_pins tuple order, same column:

  ┌─────────────┬────────────────┬────────────┬────────────┐
  │ Key pressed │ row_pins index │ Extra key  │ next index │
  ├─────────────┼────────────────┼────────────┼────────────┤
  │ F3          │ row 2          │ Next(PgDn) │ row 3      │
  ├─────────────┼────────────────┼────────────┼────────────┤
  │ Next(PgDn)  │ row 3          │ F5         │ row 4      │
  ├─────────────┼────────────────┼────────────┼────────────┤
  │ F5          │ row 4          │ F7         │ row 5      │
  ├─────────────┼────────────────┼────────────┼────────────┤
  │ F7          │ row 5          │ F9         │ row 6      │
  ├─────────────┼────────────────┼────────────┼────────────┤
  │ F8          │ row 5, col 1   │ F10        │ row 6      │
  ├─────────────┼────────────────┼────────────┼────────────┤
  │ F9          │ row 6          │ END        │ row 7      │
  └─────────────┴────────────────┴────────────┴────────────┘

  That's a continuous chain, rows 2→3→4→5→6→7, in exactly the order the rows
  appear in code.py:17-20 (GP13, GP14, GP20, GP15, GP22, GP21). Rows 0/1
  (F1/F2/F11/F12) aren't affected, and it doesn't wrap row 7→row 0. This is a
  textbook "adjacent row leaks into the next-scanned row" ghost — when row R is
  driven and a key is pressed, row R's line doesn't fully drop before row R+1 is
  driven, so the same column reads HIGH again on row R+1's scan. Since it only
  shows up on columns 0/1 (the F-key column) so far, either those column traces
  have more capacitance/length, or you simply haven't tested other columns on
  rows 2-7 yet (worth checking, e.g. does TAB/W ghost into Q/E?).

  This pattern could come from either side:
  - Hardware: a physical short/crosstalk between adjacent row conductors — bad
  solder joint, frayed ribbon, oxidized/misaligned connector pins — spanning
  that contiguous run of rows.
  - Software/electrical timing: CircuitPython's native keypad.KeyMatrix (the
  actual scan loop lives in C, not in this repo) not leaving enough settle time
  before switching rows, combined with column trace capacitance.

  Tests to tell them apart

  1. Enable KMK debug and watch raw scan coordinates. Set
  Debug(__name__).enabled = True in code.py:10, open the serial console, press
  just F3. If you see two distinct (row, col) events fire (r2,c0) and (r3,c0),
  the ghost is happening at the electrical/matrix level — hardware. If only one
  matrix position is scanned but two HID codes go out, it'd be a firmware bug
  (unlikely — I checked the keymap, each position maps to exactly one key).
  2. Multimeter continuity check (Pico powered off, nothing pressed): measure
  resistance between the suspect row pins/wires (e.g. between the wire going to
  GP13 and the wire going to GP14, at the ribbon connector). Near-0Ω where there
  shouldn't be any connection = confirmed hardware short.
  3. Re-order test: temporarily swap two of the affected rows' positions in the
  row_pins tuple (keeping the same physical wire-to-GPIO connections, just
  changing scan order) and update the keymap rows to match. If the ghost still
  follows the same physical wires (e.g. GP13 still leaks into GP14 regardless of
  scan order), that confirms a physical short rather than a scan-order
  artifact.

  For PrtSc (row 6, col 9, code.py:57) — KC.PSCR is a standard,
  correctly-defined HID keycode (kmk/keys.py:218), so it's not a keymap bug.
  Same first step: enable debug and press PrtSc.
  - No scan event at all → dead switch/diode/broken wire for that specific key —
  hardware.
  - Scan event appears but nothing shows in xev → check with evtest on the raw
  Linux input device (bypasses X11). It's common for desktop
  environments/screenshot tools to grab PrintScreen as a global hotkey, which
  prevents xev from ever seeing it even though the keyboard is sending it
  correctly — that would be an OS/DE config issue, not your hardware.

  Want me to make the debug-enabling edit to code.py now so you can run the
  first test?

✻ Crunched for 3m 28s

❯  YEs. make that debug change and also I just confirmed there is not short     
  between GP13 and GP14 using a multimeter                                      

  Searched for 2 patterns, read 2 files (ctrl+o to expand)

⏺ Update(code.py)
  ⎿  Added 1 line, removed 1 line
       7  from kmk.scanners.keypad import MatrixScanner
       8  from kmk.utils import Debug
       9  
      10 -Debug(__name__).enabled = False                                
      10 +Debug(__name__).enabled = True                                 
      11  
      12  # Copy this code to CIRCUITPY\code.py
      13  

⏺ Debug is now enabled (code.py:10). Copy this code.py to CIRCUITPY, then
  connect to the serial console (screen /dev/ttyACM0 115200, tio /dev/ttyACM0,
  or the Mu editor's serial panel — press Ctrl+D first if it doesn't
  auto-reload).

  With debug on, every matrix change logs a line like:
  <ticks> kmk.keyboard: KeyEvent(key_number=22, pressed=True): <Key F3>
  key_number is row_index * 11 + col_index (11 columns). For your broken keys,
  watch for these specific numbers:

  ┌────────────┬────────────┐
  │    Key     │ key_number │
  ├────────────┼────────────┤
  │ F3         │ 22         │
  ├────────────┼────────────┤
  │ Next(PgDn) │ 33         │
  ├────────────┼────────────┤
  │ F5         │ 44         │
  ├────────────┼────────────┤
  │ F7         │ 55         │
  ├────────────┼────────────┤
  │ F9         │ 66         │
  ├────────────┼────────────┤
  │ END        │ 77         │
  ├────────────┼────────────┤
  │ F8         │ 56         │
  ├────────────┼────────────┤
  │ F10        │ 67         │
  ├────────────┼────────────┤
  │ PrtSc      │ 75         │
  └────────────┴────────────┘

  Press F3 alone and watch the log: if you see two KeyEvent lines (22 and 33)
  fire back-to-back, the ghost is happening at the raw matrix-scan level —
  confirmed hardware/electrical, not a firmware keymap bug. If you only ever see
  one key_number but two HID keys reach the OS, that'd point elsewhere
  (unlikely — I've already checked the keymap and each position resolves to
  exactly one key).

  For PrtSc: press it and see if key_number=75 appears in the log at all. No log
  line = the switch/diode/wire for that key isn't making contact — hardware. A
  log line with no downstream effect would point to something at the USB/OS
  layer instead.

  On your multimeter result: ruling out GP13↔GP14 is useful, but it only clears
  one link in the chain. Worth also checking GP14↔GP20, GP20↔GP15, GP15↔GP22,
  and GP22↔GP21 (the other row-pin pairs in the ghost chain) — and try
  wiggling/flexing the ribbon connector while measuring, since a static at-rest
  continuity check can miss an intermittent connector fault that only shows up
  under slight mechanical stress or when actually seated.

✻ Baked for 52s

※ recap: We're debugging why some keyboard keys double-register and PrtSc doesn't work at all. I just enabled debug logging in code.py; next step is for you to copy it to CIRCUITPY, watch the serial console, and press F3 and PrtSc to see what logs. (disable recaps in /config)

❯ add to the readme a section explaining how to list tty devices and select the 
  right one to connect to pico. Explain the full procedure how you open serial  
  comms using `screen`                                                          

  Read 1 file (ctrl+o to expand)

⏺ I'll insert a new section here explaining how to find and connect to the
  Pico's serial device, right before "Verify CircuitPython" since that's the
  first place the README assumes you already have a serial console open.

⏺ Update(README.md)
  ⎿  Added 51 lines
       83  
       84  ---
       85  
       86 +# Connecting to the Serial Console                            
       87 +                                                              
       88 +The Pico exposes a USB serial (CDC) device once CircuitPython 
          +is installed. This is how you see `print()` output, KMK debug 
          +logs, and the REPL.                                           
       89 +                                                              
       90 +## 1. List available tty devices                              
       91 +                                                              
       92 +**macOS:**                                                    
       93 +                                                              
       94 +```bash                                                       
       95 +ls /dev/tty.*                                                 
       96 +```                                                           
       97 +                                                              
       98 +The Pico shows up as something like `/dev/tty.usbmodem14101`. 
       99 +                                                              
      100 +**Linux (including Raspberry Pi):**                           
      101 +                                                              
      102 +```bash                                                       
      103 +ls /dev/ttyACM*                                               
      104 +```                                                           
      105 +                                                              
      106 +The Pico is usually `/dev/ttyACM0` (or the next free number if
          + other USB-serial devices are already connected).             
      107 +                                                              
      108 +If several devices are listed and you're not sure which one is
          + the Pico, unplug it, re-run the `ls` command, plug it back in
          +, and re-run again — the device that appears is the Pico. On L
          +inux you can also confirm with:                               
      109 +                                                              
      110 +```bash                                                       
      111 +ls -la /dev/serial/by-id/                                     
      112 +```                                                           
      113 +                                                              
      114 +which prints a descriptive name (e.g. containing `Raspberry_Pi
          +_Pico` or `CircuitPython`) instead of a generic device number.
      115 +                                                              
      116 +## 2. Open the serial console with `screen`                   
      117 +                                                              
      118 +```bash                                                       
      119 +screen /dev/tty.usbmodem14101 115200                          
      120 +```                                                           
      121 +                                                              
      122 +(substitute the actual device path from step 1; the baud rate 
          +`115200` is conventional and CircuitPython ignores it over USB
          +, but you still need to supply a value).                      
      123 +                                                              
      124 +You should land on a blank terminal connected to the board. If
          + `code.py` is running, any `print()` output or KMK debug lines
          + will stream in as they happen. Press Enter if you see nothing
          + — sometimes the first line is swallowed by `screen` attaching
          + mid-output.                                                  
      125 +                                                              
      126 +## 3. Useful keys once connected                              
      127 +                                                              
      128 +- **Ctrl+D** — soft-reboot: reloads and re-runs `code.py`.    
      129 +- **Ctrl+C** — interrupt the running program and drop into the
          + REPL.                                                        
      130 +- **Ctrl+A** then **K**, then **y** — kill the `screen` sessio
          +n (disconnects so another program, like Mu, can open the port)
          +.                                                             
      131 +- **Ctrl+A** then **D** — detach without killing the session (
          +reattach later with `screen -r`).                             
      132 +                                                              
      133 +Only one program can hold the serial port open at a time — if 
          +`screen` won't connect, make sure Mu, `tio`, Arduino IDE's ser
          +ial monitor, etc. aren't already attached to the same device. 
      134 +                                                              
      135 +---                                                           
      136 +                                                              
      137  # Verify CircuitPython
      138  
      139  Create `code.py`

⏺ Added a "Connecting to the Serial Console" section covering listing tty
  devices on macOS/Linux, identifying the Pico, opening it with screen, and the
  key commands (Ctrl+D reload, Ctrl+C for REPL, Ctrl+A K to quit screen).

✻ Cogitated for 25s

※ recap: You're debugging keyboard ghosting and a dead PrtSc key on the Toshiba T1200XE Pico firmware, and just documented how to connect via screen. Next: reconnect over serial with debug logging enabled and press F3/PrtSc to check which key_numbers actually fire. (disable recaps in /config)

❯ OK, just pressing F3 yields this                                              
                                                                                
  395179 kmk.keyboard: <Event: key_number 22 pressed>: KeyboardKey(code=60)     
  395182 kmk.keyboard: coordkeys_pressed={22: KeyboardKey(code=60)}             
  395185 kmk.keyboard: keys_pressed={KeyboardKey(code=60)}                      
  395221 kmk.keyboard: <Event: key_number 33 pressed>: KeyboardKey(code=78)     
  395224 kmk.keyboard: coordkeys_pressed={22: KeyboardKey(code=60), 33:         
  KeyboardKey(code=78)}                                                         
  395228 kmk.keyboard: keys_pressed={KeyboardKey(code=60),                      
  KeyboardKey(code=78)}                                                         
  395297 kmk.keyboard: <Event: key_number 22 released>: KeyboardKey(code=60)    
  395300 kmk.keyboard: coordkeys_pressed={33: KeyboardKey(code=78)}             
  395303 kmk.keyboard: keys_pressed={KeyboardKey(code=78)}                      
  395308 kmk.keyboard: <Event: key_number 33 released>: KeyboardKey(code=78)    
  395311 kmk.keyboard: coordkeys_pressed={}                                     
  397613 kmk.keyboard: <Event: key_number 22 pressed>: KeyboardKey(code=60)     
  397616 kmk.keyboard: coordkeys_pressed={22: KeyboardKey(code=60)}             
  397619 kmk.keyboard: keys_pressed={KeyboardKey(code=60)}                      
  397685 kmk.keyboard: <Event: key_number 33 pressed>: KeyboardKey(code=78)     
  397689 kmk.keyboard: coordkeys_pressed={22: KeyboardKey(code=60), 33:         
  KeyboardKey(code=78)}                                                         
  397692 kmk.keyboard: keys_pressed={KeyboardKey(code=60),                      
  KeyboardKey(code=78)}                                                         
  397720 kmk.keyboard: <Event: key_number 33 released>: KeyboardKey(code=78)    
  397723 kmk.keyboard: coordkeys_pressed={22: KeyboardKey(code=60)}             
  397726 kmk.keyboard: keys_pressed={KeyboardKey(code=60)}                      
  397731 kmk.keyboard: <Event: key_number 22 released>: KeyboardKey(code=60)    
  397734 kmk.keyboard: coordkeys_pressed={}                                     
  398920 kmk.keyboard: <Event: key_number 22 pressed>: KeyboardKey(code=60)     
  398922 kmk.keyboard: coordkeys_pressed={22: KeyboardKey(code=60)}             
  398925 kmk.keyboard: keys_pressed={KeyboardKey(code=60)}                      
  398946 kmk.keyboard: <Event: key_number 33 pressed>: KeyboardKey(code=78)     
  398949 kmk.keyboard: coordkeys_pressed={22: KeyboardKey(code=60), 33:         
  KeyboardKey(code=78)}                                                         
  398953 kmk.keyboard: keys_pressed={KeyboardKey(code=60),                      
  KeyboardKey(code=78)}                                                         
  399022 kmk.keyboard: <Event: key_number 33 released>: KeyboardKey(code=78)    
  399025 kmk.keyboard: coordkeys_pressed={22: KeyboardKey(code=60)}             
  399028 kmk.keyboard: keys_pressed={KeyboardKey(code=60)}                      
  399033 kmk.keyboard: <Event: key_number 22 released>: KeyboardKey(code=60)    
  399036 kmk.keyboard: coordkeys_pressed={}                                     

⏺ That log confirms the ghost is happening at the raw matrix-scan level, not in
  firmware — two genuinely separate key_number events (22 and 33) fire from one
  press of F3. So it's hardware. But the timing rules out a simple wire-to-wire
  short, and points somewhere more specific:

  - key_number 33 (Next) fires 42–72ms after key_number 22 (F3), not in the same
  scan cycle. A hard short between the row lines would assert both almost
  instantly (within one ~2ms scan). This lag looks like something taking time to
  make contact.
  - The release order flips between attempts — 22-then-33 released in trial 1,
  but 33-then-22 in trials 2 and 3. A fixed electrical short would behave
  consistently; this doesn't.

  That pattern — delayed, inconsistent, tied to a specific pair of keys that are
  physically adjacent on the keyboard (F3 sits right above Next/PgDn in that
  vertical F-key column) — is much more characteristic of a worn or cracked 
  membrane/flex-circuit trace than a wiring short. On old membrane keyboards
  like this one, pressing a key can slightly deform the membrane; if there's a
  crack or worn conductive trace near the boundary between two adjacent key
  pads, that flex can momentarily bridge into the neighbor's contact — with
  exactly this kind of soft, variable-delay, order-inconsistent behavior. It
  would also explain why your multimeter check (at rest, unpressed) found
  nothing: the bridging only happens under the mechanical pressure of an actual
  keypress, not when the keyboard is idle.

  Since the whole chain (F3→Next→F5→F7→F9→End) runs down that same physical
  column, this suggests wear or damage along that entire strip of the membrane,
  not just one spot.

  Two follow-ups worth doing:
  1. Continuity test while pressed: hold F3 down and check for continuity
  between the row2/row3 conductors (or right at the keyboard's ribbon connector
  pins) while pressed — a short that only appears under pressure would confirm
  the membrane-crack theory directly.
  2. Visual inspection: if the keyboard can be opened, look at the membrane/flex
  circuit in the F3–End column for visible cracks, worn silver-ink traces, or
  debris between adjacent pads.

  Separately — can you press PrtSc and paste the log? I want to see whether
  key_number 75 appears at all.

✻ Baked for 45s

❯ 721131 kmk.keyboard: <Event: key_number 75 pressed>: KeyboardKey(code=70)     
  721134 kmk.keyboard: coordkeys_pressed={75: KeyboardKey(code=70)}             
  721137 kmk.keyboard: keys_pressed={KeyboardKey(code=70)}                      
  721209 kmk.keyboard: <Event: key_number 75 released>: KeyboardKey(code=70)    
  721212 kmk.keyboard: coordkeys_pressed={}                                     

⏺ Good news for hardware/firmware: key_number 75 fires correctly and resolves to
  KeyboardKey(code=70) — code 70 (0x46) is exactly the standard HID usage for
  Print Screen. So the matrix, the switch, and KMK are all doing their job
  correctly and sending the right HID report. This is not a hardware fault.

  That pushes the problem downstream, to the Linux input layer or X11/desktop
  environment. Next step: bypass xev entirely and watch the raw kernel input
  event.

  1. Find the Pico's input device:

  cat /proc/bus/input/devices | grep -A5 -i "adafruit\|pico\|kmk"

  Look for a line like Handlers=... eventX — note that eventX number. (If
  nothing matches, run ls /dev/input/by-id/ instead and look for a *-event-kbd
  entry mentioning the Pico.)

  2. Watch raw kernel events:

  sudo evtest /dev/input/eventX

  Press PrtSc and see what happens:

  - If you see a line like EV_KEY / KEY_SYSRQ or EV_KEY / KEY_PRINT reported
  there — the key is reaching the kernel input layer just fine, and the problem
  is X11/your desktop environment eating it before xev's window ever sees it.
  This is extremely common: screenshot utilities (GNOME Screenshot, Flameshot,
  scrot bound via a WM shortcut, etc.) register PrintScreen as a global grab,
  which means X delivers the event only to the grabbing client, never to other
  windows including xev. Worth checking xfce4-keyboard-settings / GNOME Settings
  → Keyboard Shortcuts / your WM config for anything bound to Print Screen, and
  temporarily disabling it to retest in xev.
  - If evtest shows nothing when you press PrtSc, then the HID report genuinely
  isn't reaching the kernel despite KMK sending it — that would be a real
  USB/HID-layer bug worth digging into further (unlikely given the log you
  showed, but let's confirm).

  Can you run that and paste what evtest shows for PrtSc?
✻ Baked for 18s

❯ Let's not solve PrtScr, I am OK for now.                                      
                                                                                
  I pressed F3 5 times, can you reconfirm your theory?                          
                                                                                
  758319 kmk.keyboard: <Event: key_number 22 pressed>: KeyboardKey(code=60)     
  758322 kmk.keyboard: coordkeys_pressed={22: KeyboardKey(code=60)}             
  758324 kmk.keyboard: keys_pressed={KeyboardKey(code=60)}                      
  758380 kmk.keyboard: <Event: key_number 33 pressed>: KeyboardKey(code=78)     
  758383 kmk.keyboard: coordkeys_pressed={22: KeyboardKey(code=60), 33:         
  KeyboardKey(code=78)}                                                         
  758387 kmk.keyboard: keys_pressed={KeyboardKey(code=60),                      
  KeyboardKey(code=78)}                                                         
  758412 kmk.keyboard: <Event: key_number 33 released>: KeyboardKey(code=78)    
  758416 kmk.keyboard: coordkeys_pressed={22: KeyboardKey(code=60)}             
  758418 kmk.keyboard: keys_pressed={KeyboardKey(code=60)}                      
  758422 kmk.keyboard: <Event: key_number 22 released>: KeyboardKey(code=60)    
  758425 kmk.keyboard: coordkeys_pressed={}                                     
  759727 kmk.keyboard: <Event: key_number 22 pressed>: KeyboardKey(code=60)     
  759730 kmk.keyboard: coordkeys_pressed={22: KeyboardKey(code=60)}             
  759733 kmk.keyboard: keys_pressed={KeyboardKey(code=60)}                      
  759739 kmk.keyboard: <Event: key_number 33 pressed>: KeyboardKey(code=78)     
  759742 kmk.keyboard: coordkeys_pressed={22: KeyboardKey(code=60), 33:         
  KeyboardKey(code=78)}                                                         
  759746 kmk.keyboard: keys_pressed={KeyboardKey(code=60),                      
  KeyboardKey(code=78)}                                                         
  759825 kmk.keyboard: <Event: key_number 22 released>: KeyboardKey(code=60)    
  759828 kmk.keyboard: coordkeys_pressed={33: KeyboardKey(code=78)}             
  759831 kmk.keyboard: keys_pressed={KeyboardKey(code=78)}                      
  759836 kmk.keyboard: <Event: key_number 33 released>: KeyboardKey(code=78)    
  759839 kmk.keyboard: coordkeys_pressed={}                                     
  760891 kmk.keyboard: <Event: key_number 22 pressed>: KeyboardKey(code=60)     
  760894 kmk.keyboard: coordkeys_pressed={22: KeyboardKey(code=60)}             
  760897 kmk.keyboard: keys_pressed={KeyboardKey(code=60)}                      
  760919 kmk.keyboard: <Event: key_number 33 pressed>: KeyboardKey(code=78)     
  760922 kmk.keyboard: coordkeys_pressed={22: KeyboardKey(code=60), 33:         
  KeyboardKey(code=78)}                                                         
  760925 kmk.keyboard: keys_pressed={KeyboardKey(code=60),                      
  KeyboardKey(code=78)}                                                         
  760979 kmk.keyboard: <Event: key_number 33 released>: KeyboardKey(code=78)    
  760982 kmk.keyboard: coordkeys_pressed={22: KeyboardKey(code=60)}             
  760985 kmk.keyboard: keys_pressed={KeyboardKey(code=60)}                      
  760990 kmk.keyboard: <Event: key_number 22 released>: KeyboardKey(code=60)    
  760993 kmk.keyboard: coordkeys_pressed={}                                     
  764312 kmk.keyboard: <Event: key_number 22 pressed>: KeyboardKey(code=60)     
  764315 kmk.keyboard: coordkeys_pressed={22: KeyboardKey(code=60)}             
  764318 kmk.keyboard: keys_pressed={KeyboardKey(code=60)}                      
  764415 kmk.keyboard: <Event: key_number 22 released>: KeyboardKey(code=60)    
  764418 kmk.keyboard: coordkeys_pressed={}                                     
  765712 kmk.keyboard: <Event: key_number 22 pressed>: KeyboardKey(code=60)     
  765714 kmk.keyboard: coordkeys_pressed={22: KeyboardKey(code=60)}             
  765717 kmk.keyboard: keys_pressed={KeyboardKey(code=60)}                      
  765761 kmk.keyboard: <Event: key_number 33 pressed>: KeyboardKey(code=78)     
  765764 kmk.keyboard: coordkeys_pressed={22: KeyboardKey(code=60), 33:         
  KeyboardKey(code=78)}                                                         
  765768 kmk.keyboard: keys_pressed={KeyboardKey(code=60),                      
  KeyboardKey(code=78)}                                                         
  765804 kmk.keyboard: <Event: key_number 33 released>: KeyboardKey(code=78)    
  765807 kmk.keyboard: coordkeys_pressed={22: KeyboardKey(code=60)}             
  765810 kmk.keyboard: keys_pressed={KeyboardKey(code=60)}                      
  765814 kmk.keyboard: <Event: key_number 22 released>: KeyboardKey(code=60)    
  765818 kmk.keyboard: coordkeys_pressed={}                                     

⏺ This data is even more conclusive — and refines the theory further.

  ┌───────┬───────────────────┬───────────────┬───────────────┐
  │ Press │ Ghost (33) fired? │ Lag before 33 │ Release order │
  ├───────┼───────────────────┼───────────────┼───────────────┤
  │ 1     │ Yes               │ 61ms          │ 33 then 22    │
  ├───────┼───────────────────┼───────────────┼───────────────┤
  │ 2     │ Yes               │ 12ms          │ 22 then 33    │
  ├───────┼───────────────────┼───────────────┼───────────────┤
  │ 3     │ Yes               │ 28ms          │ 33 then 22    │
  ├───────┼───────────────────┼───────────────┼───────────────┤
  │ 4     │ No                │ —             │ —             │
  ├───────┼───────────────────┼───────────────┼───────────────┤
  │ 5     │ Yes               │ 49ms          │ 33 then 22    │
  └───────┴───────────────────┴───────────────┴───────────────┘

  Press 4 produced zero ghosting — a clean, single key_number 22 event with no
  33 at all. That's the key new fact: it rules out a fixed short (a solder
  bridge or permanent wire-to-wire short would fire every single time, with
  roughly consistent timing). Instead you're getting the ghost ~80% of the time,
  with lag ranging from 12ms to 61ms and no consistent release order.

  This is exactly what you'd expect from a marginal, pressure-dependent 
  mechanical contact rather than an electrical fault: something in the
  keyboard's physical construction (most likely a worn/cracked conductive trace
  on the membrane, or debris/contamination between the F3 and Next pads) that
  only bridges the two contacts when the key is pressed hard enough, fast
  enough, or at the right angle — and sometimes doesn't bridge at all. That
  fully explains the variable lag and the one clean press.

  So: confirmed hardware, and now narrowed from "short somewhere in the row
  wiring" to "intermittent, force/angle-sensitive contact fault localized to the
  physical keys in that F-key column, most likely on the membrane itself" —
  worth opening the keyboard and inspecting/cleaning that column's membrane
  contacts if you want to pursue a repair.

✻ Worked for 17s

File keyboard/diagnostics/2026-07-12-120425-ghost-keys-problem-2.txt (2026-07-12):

╭─── Claude Code v2.1.201 ─────────────────────────────────────────────────────╮
│                                                    │ Tips for getting        │
│                 Welcome back Alex!                 │ started                 │
│                                                    │ Run /init to create a … │
│                       ▐▛███▜▌                      │ ─────────────────────── │
│                      ▝▜█████▛▘                     │ What's new              │
│                        ▘▘ ▝▝                       │ Claude Sonnet 5 sessio… │
│    Sonnet 5 · Claude Pro · zhukovin@gmail.com's    │ Changed `AskUserQuesti… │
│    Organization                                    │ Changed the "default" … │
│           ~/code/toshiba-t1200xe-keyboard          │ /release-notes for more │
╰──────────────────────────────────────────────────────────────────────────────╯

 ▎ Extended: Fable 5 is included in your weekly limit
 ▎ Through July 12, you can use up to 50% of your weekly usage limit on Fable 5. If you hit your limit, you can continue on Fable 5 with usage credits. Fable 5 draws down usage faster than Opus 4.8. Run /model and select Fable to use it. Learn more
   +1 more · /status

❯ Here is the problem that I am facing with this keyboard. When I press some    
  keys, they produce 2 keys (the rest work just fine). Here are the broken      
  keys:                                                                         
  F3 -> F3, Next (PgDn)                                                         
  F5 -> F5, F7                                                                  
  F7 -> F7, F9                                                                  
  F8 -> F8, F10                                                                 
  F9 -> F9,END                                                                  
  Next (PgDn) -> Next, F5                                                       
                                                                                
  I used rpi's utility xev to monitor keyboard events, so the key names might   
  be unusual (like Next, which means PgDn)                                      
                                                                                
  The other problem is that PrtSc key does not produce any linux event.         
                                                                                
  Please help me debug this, I want to check whether it is a hardware or        
  software problem.                                                             

  Searched for 3 patterns, read 4 files (ctrl+o to expand)

⏺ I found the project — this is a KMK/CircuitPython firmware for a Raspberry Pi
  Pico that scans the original Toshiba keyboard matrix (code.py:34-40, row/col
  pins at code.py:17-26). Mapping your reported keys against the matrix in
  code.py:49-59 reveals a clean pattern.

  The ghosting pattern

  Every broken key maps to (row, col0-or-1), and the "extra" key is always the
  next row in the row_pins tuple order, same column:

  ┌─────────────┬────────────────┬────────────┬────────────┐
  │ Key pressed │ row_pins index │ Extra key  │ next index │
  ├─────────────┼────────────────┼────────────┼────────────┤
  │ F3          │ row 2          │ Next(PgDn) │ row 3      │
  ├─────────────┼────────────────┼────────────┼────────────┤
  │ Next(PgDn)  │ row 3          │ F5         │ row 4      │
  ├─────────────┼────────────────┼────────────┼────────────┤
  │ F5          │ row 4          │ F7         │ row 5      │
  ├─────────────┼────────────────┼────────────┼────────────┤
  │ F7          │ row 5          │ F9         │ row 6      │
  ├─────────────┼────────────────┼────────────┼────────────┤
  │ F8          │ row 5, col 1   │ F10        │ row 6      │
  ├─────────────┼────────────────┼────────────┼────────────┤
  │ F9          │ row 6          │ END        │ row 7      │
  └─────────────┴────────────────┴────────────┴────────────┘

  That's a continuous chain, rows 2→3→4→5→6→7, in exactly the order the rows
  appear in code.py:17-20 (GP13, GP14, GP20, GP15, GP22, GP21). Rows 0/1
  (F1/F2/F11/F12) aren't affected, and it doesn't wrap row 7→row 0. This is a
  textbook "adjacent row leaks into the next-scanned row" ghost — when row R is
  driven and a key is pressed, row R's line doesn't fully drop before row R+1 is
  driven, so the same column reads HIGH again on row R+1's scan. Since it only
  shows up on columns 0/1 (the F-key column) so far, either those column traces
  have more capacitance/length, or you simply haven't tested other columns on
  rows 2-7 yet (worth checking, e.g. does TAB/W ghost into Q/E?).

  This pattern could come from either side:
  - Hardware: a physical short/crosstalk between adjacent row conductors — bad
  solder joint, frayed ribbon, oxidized/misaligned connector pins — spanning
  that contiguous run of rows.
  - Software/electrical timing: CircuitPython's native keypad.KeyMatrix (the
  actual scan loop lives in C, not in this repo) not leaving enough settle time
  before switching rows, combined with column trace capacitance.

  Tests to tell them apart

  1. Enable KMK debug and watch raw scan coordinates. Set
  Debug(__name__).enabled = True in code.py:10, open the serial console, press
  just F3. If you see two distinct (row, col) events fire (r2,c0) and (r3,c0),
  the ghost is happening at the electrical/matrix level — hardware. If only one
  matrix position is scanned but two HID codes go out, it'd be a firmware bug
  (unlikely — I checked the keymap, each position maps to exactly one key).
  2. Multimeter continuity check (Pico powered off, nothing pressed): measure
  resistance between the suspect row pins/wires (e.g. between the wire going to
  GP13 and the wire going to GP14, at the ribbon connector). Near-0Ω where there
  shouldn't be any connection = confirmed hardware short.
  3. Re-order test: temporarily swap two of the affected rows' positions in the
  row_pins tuple (keeping the same physical wire-to-GPIO connections, just
  changing scan order) and update the keymap rows to match. If the ghost still
  follows the same physical wires (e.g. GP13 still leaks into GP14 regardless of
  scan order), that confirms a physical short rather than a scan-order
  artifact.

  For PrtSc (row 6, col 9, code.py:57) — KC.PSCR is a standard,
  correctly-defined HID keycode (kmk/keys.py:218), so it's not a keymap bug.
  Same first step: enable debug and press PrtSc.
  - No scan event at all → dead switch/diode/broken wire for that specific key —
  hardware.
  - Scan event appears but nothing shows in xev → check with evtest on the raw
  Linux input device (bypasses X11). It's common for desktop
  environments/screenshot tools to grab PrintScreen as a global hotkey, which
  prevents xev from ever seeing it even though the keyboard is sending it
  correctly — that would be an OS/DE config issue, not your hardware.

  Want me to make the debug-enabling edit to code.py now so you can run the
  first test?

✻ Worked for 3m 28s

❯  YEs. make that debug change and also I just confirmed there is not short     
  between GP13 and GP14 using a multimeter                                      

  Searched for 2 patterns, read 2 files (ctrl+o to expand)

⏺ Update(code.py)
  ⎿  Added 1 line, removed 1 line
       7  from kmk.scanners.keypad import MatrixScanner
       8  from kmk.utils import Debug
       9  
      10 -Debug(__name__).enabled = False                                
      10 +Debug(__name__).enabled = True                                 
      11  
      12  # Copy this code to CIRCUITPY\code.py
      13  

⏺ Debug is now enabled (code.py:10). Copy this code.py to CIRCUITPY, then
  connect to the serial console (screen /dev/ttyACM0 115200, tio /dev/ttyACM0,
  or the Mu editor's serial panel — press Ctrl+D first if it doesn't
  auto-reload).

  With debug on, every matrix change logs a line like:
  <ticks> kmk.keyboard: KeyEvent(key_number=22, pressed=True): <Key F3>
  key_number is row_index * 11 + col_index (11 columns). For your broken keys,
  watch for these specific numbers:

  ┌────────────┬────────────┐
  │    Key     │ key_number │
  ├────────────┼────────────┤
  │ F3         │ 22         │
  ├────────────┼────────────┤
  │ Next(PgDn) │ 33         │
  ├────────────┼────────────┤
  │ F5         │ 44         │
  ├────────────┼────────────┤
  │ F7         │ 55         │
  ├────────────┼────────────┤
  │ F9         │ 66         │
  ├────────────┼────────────┤
  │ END        │ 77         │
  ├────────────┼────────────┤
  │ F8         │ 56         │
  ├────────────┼────────────┤
  │ F10        │ 67         │
  ├────────────┼────────────┤
  │ PrtSc      │ 75         │
  └────────────┴────────────┘

  Press F3 alone and watch the log: if you see two KeyEvent lines (22 and 33)
  fire back-to-back, the ghost is happening at the raw matrix-scan level —
  confirmed hardware/electrical, not a firmware keymap bug. If you only ever see
  one key_number but two HID keys reach the OS, that'd point elsewhere
  (unlikely — I've already checked the keymap and each position resolves to
  exactly one key).

  For PrtSc: press it and see if key_number=75 appears in the log at all. No log
  line = the switch/diode/wire for that key isn't making contact — hardware. A
  log line with no downstream effect would point to something at the USB/OS
  layer instead.

  On your multimeter result: ruling out GP13↔GP14 is useful, but it only clears
  one link in the chain. Worth also checking GP14↔GP20, GP20↔GP15, GP15↔GP22,
  and GP22↔GP21 (the other row-pin pairs in the ghost chain) — and try
  wiggling/flexing the ribbon connector while measuring, since a static at-rest
  continuity check can miss an intermittent connector fault that only shows up
  under slight mechanical stress or when actually seated.

✻ Churned for 52s

※ recap: We're debugging why some keyboard keys double-register and PrtSc doesn't work at all. I just enabled debug logging in code.py; next step is for you to copy it to CIRCUITPY, watch the serial console, and press F3 and PrtSc to see what logs. (disable recaps in /config)

❯ add to the readme a section explaining how to list tty devices and select the 
  right one to connect to pico. Explain the full procedure how you open serial  
  comms using `screen`                                                          

  Read 1 file (ctrl+o to expand)

⏺ I'll insert a new section here explaining how to find and connect to the
  Pico's serial device, right before "Verify CircuitPython" since that's the
  first place the README assumes you already have a serial console open.

⏺ Update(README.md)
  ⎿  Added 51 lines
       83  
       84  ---
       85  
       86 +# Connecting to the Serial Console                            
       87 +                                                              
       88 +The Pico exposes a USB serial (CDC) device once CircuitPython 
          +is installed. This is how you see `print()` output, KMK debug 
          +logs, and the REPL.                                           
       89 +                                                              
       90 +## 1. List available tty devices                              
       91 +                                                              
       92 +**macOS:**                                                    
       93 +                                                              
       94 +```bash                                                       
       95 +ls /dev/tty.*                                                 
       96 +```                                                           
       97 +                                                              
       98 +The Pico shows up as something like `/dev/tty.usbmodem14101`. 
       99 +                                                              
      100 +**Linux (including Raspberry Pi):**                           
      101 +                                                              
      102 +```bash                                                       
      103 +ls /dev/ttyACM*                                               
      104 +```                                                           
      105 +                                                              
      106 +The Pico is usually `/dev/ttyACM0` (or the next free number if
          + other USB-serial devices are already connected).             
      107 +                                                              
      108 +If several devices are listed and you're not sure which one is
          + the Pico, unplug it, re-run the `ls` command, plug it back in
          +, and re-run again — the device that appears is the Pico. On L
          +inux you can also confirm with:                               
      109 +                                                              
      110 +```bash                                                       
      111 +ls -la /dev/serial/by-id/                                     
      112 +```                                                           
      113 +                                                              
      114 +which prints a descriptive name (e.g. containing `Raspberry_Pi
          +_Pico` or `CircuitPython`) instead of a generic device number.
      115 +                                                              
      116 +## 2. Open the serial console with `screen`                   
      117 +                                                              
      118 +```bash                                                       
      119 +screen /dev/tty.usbmodem14101 115200                          
      120 +```                                                           
      121 +                                                              
      122 +(substitute the actual device path from step 1; the baud rate 
          +`115200` is conventional and CircuitPython ignores it over USB
          +, but you still need to supply a value).                      
      123 +                                                              
      124 +You should land on a blank terminal connected to the board. If
          + `code.py` is running, any `print()` output or KMK debug lines
          + will stream in as they happen. Press Enter if you see nothing
          + — sometimes the first line is swallowed by `screen` attaching
          + mid-output.                                                  
      125 +                                                              
      126 +## 3. Useful keys once connected                              
      127 +                                                              
      128 +- **Ctrl+D** — soft-reboot: reloads and re-runs `code.py`.    
      129 +- **Ctrl+C** — interrupt the running program and drop into the
          + REPL.                                                        
      130 +- **Ctrl+A** then **K**, then **y** — kill the `screen` sessio
          +n (disconnects so another program, like Mu, can open the port)
          +.                                                             
      131 +- **Ctrl+A** then **D** — detach without killing the session (
          +reattach later with `screen -r`).                             
      132 +                                                              
      133 +Only one program can hold the serial port open at a time — if 
          +`screen` won't connect, make sure Mu, `tio`, Arduino IDE's ser
          +ial monitor, etc. aren't already attached to the same device. 
      134 +                                                              
      135 +---                                                           
      136 +                                                              
      137  # Verify CircuitPython
      138  
      139  Create `code.py`

⏺ Added a "Connecting to the Serial Console" section covering listing tty
  devices on macOS/Linux, identifying the Pico, opening it with screen, and the
  key commands (Ctrl+D reload, Ctrl+C for REPL, Ctrl+A K to quit screen).

✻ Cogitated for 25s

※ recap: You're debugging keyboard ghosting and a dead PrtSc key on the Toshiba T1200XE Pico firmware, and just documented how to connect via screen. Next: reconnect over serial with debug logging enabled and press F3/PrtSc to check which key_numbers actually fire. (disable recaps in /config)

❯ OK, just pressing F3 yields this                                              
                                                                                
  395179 kmk.keyboard: <Event: key_number 22 pressed>: KeyboardKey(code=60)     
  395182 kmk.keyboard: coordkeys_pressed={22: KeyboardKey(code=60)}             
  395185 kmk.keyboard: keys_pressed={KeyboardKey(code=60)}                      
  395221 kmk.keyboard: <Event: key_number 33 pressed>: KeyboardKey(code=78)     
  395224 kmk.keyboard: coordkeys_pressed={22: KeyboardKey(code=60), 33:         
  KeyboardKey(code=78)}                                                         
  395228 kmk.keyboard: keys_pressed={KeyboardKey(code=60),                      
  KeyboardKey(code=78)}                                                         
  395297 kmk.keyboard: <Event: key_number 22 released>: KeyboardKey(code=60)    
  395300 kmk.keyboard: coordkeys_pressed={33: KeyboardKey(code=78)}             
  395303 kmk.keyboard: keys_pressed={KeyboardKey(code=78)}                      
  395308 kmk.keyboard: <Event: key_number 33 released>: KeyboardKey(code=78)    
  395311 kmk.keyboard: coordkeys_pressed={}                                     
  397613 kmk.keyboard: <Event: key_number 22 pressed>: KeyboardKey(code=60)     
  397616 kmk.keyboard: coordkeys_pressed={22: KeyboardKey(code=60)}             
  397619 kmk.keyboard: keys_pressed={KeyboardKey(code=60)}                      
  397685 kmk.keyboard: <Event: key_number 33 pressed>: KeyboardKey(code=78)     
  397689 kmk.keyboard: coordkeys_pressed={22: KeyboardKey(code=60), 33:         
  KeyboardKey(code=78)}                                                         
  397692 kmk.keyboard: keys_pressed={KeyboardKey(code=60),                      
  KeyboardKey(code=78)}                                                         
  397720 kmk.keyboard: <Event: key_number 33 released>: KeyboardKey(code=78)    
  397723 kmk.keyboard: coordkeys_pressed={22: KeyboardKey(code=60)}             
  397726 kmk.keyboard: keys_pressed={KeyboardKey(code=60)}                      
  397731 kmk.keyboard: <Event: key_number 22 released>: KeyboardKey(code=60)    
  397734 kmk.keyboard: coordkeys_pressed={}                                     
  398920 kmk.keyboard: <Event: key_number 22 pressed>: KeyboardKey(code=60)     
  398922 kmk.keyboard: coordkeys_pressed={22: KeyboardKey(code=60)}             
  398925 kmk.keyboard: keys_pressed={KeyboardKey(code=60)}                      
  398946 kmk.keyboard: <Event: key_number 33 pressed>: KeyboardKey(code=78)     
  398949 kmk.keyboard: coordkeys_pressed={22: KeyboardKey(code=60), 33:         
  KeyboardKey(code=78)}                                                         
  398953 kmk.keyboard: keys_pressed={KeyboardKey(code=60),                      
  KeyboardKey(code=78)}                                                         
  399022 kmk.keyboard: <Event: key_number 33 released>: KeyboardKey(code=78)    
  399025 kmk.keyboard: coordkeys_pressed={22: KeyboardKey(code=60)}             
  399028 kmk.keyboard: keys_pressed={KeyboardKey(code=60)}                      
  399033 kmk.keyboard: <Event: key_number 22 released>: KeyboardKey(code=60)    
  399036 kmk.keyboard: coordkeys_pressed={}                                     

⏺ That log confirms the ghost is happening at the raw matrix-scan level, not in
  firmware — two genuinely separate key_number events (22 and 33) fire from one
  press of F3. So it's hardware. But the timing rules out a simple wire-to-wire
  short, and points somewhere more specific:

  - key_number 33 (Next) fires 42–72ms after key_number 22 (F3), not in the same
  scan cycle. A hard short between the row lines would assert both almost
  instantly (within one ~2ms scan). This lag looks like something taking time to
  make contact.
  - The release order flips between attempts — 22-then-33 released in trial 1,
  but 33-then-22 in trials 2 and 3. A fixed electrical short would behave
  consistently; this doesn't.

  That pattern — delayed, inconsistent, tied to a specific pair of keys that are
  physically adjacent on the keyboard (F3 sits right above Next/PgDn in that
  vertical F-key column) — is much more characteristic of a worn or cracked 
  membrane/flex-circuit trace than a wiring short. On old membrane keyboards
  like this one, pressing a key can slightly deform the membrane; if there's a
  crack or worn conductive trace near the boundary between two adjacent key
  pads, that flex can momentarily bridge into the neighbor's contact — with
  exactly this kind of soft, variable-delay, order-inconsistent behavior. It
  would also explain why your multimeter check (at rest, unpressed) found
  nothing: the bridging only happens under the mechanical pressure of an actual
  keypress, not when the keyboard is idle.

  Since the whole chain (F3→Next→F5→F7→F9→End) runs down that same physical
  column, this suggests wear or damage along that entire strip of the membrane,
  not just one spot.

  Two follow-ups worth doing:
  1. Continuity test while pressed: hold F3 down and check for continuity
  between the row2/row3 conductors (or right at the keyboard's ribbon connector
  pins) while pressed — a short that only appears under pressure would confirm
  the membrane-crack theory directly.
  2. Visual inspection: if the keyboard can be opened, look at the membrane/flex
  circuit in the F3–End column for visible cracks, worn silver-ink traces, or
  debris between adjacent pads.

  Separately — can you press PrtSc and paste the log? I want to see whether
  key_number 75 appears at all.

✻ Crunched for 45s

❯ 721131 kmk.keyboard: <Event: key_number 75 pressed>: KeyboardKey(code=70)     
  721134 kmk.keyboard: coordkeys_pressed={75: KeyboardKey(code=70)}             
  721137 kmk.keyboard: keys_pressed={KeyboardKey(code=70)}                      
  721209 kmk.keyboard: <Event: key_number 75 released>: KeyboardKey(code=70)    
  721212 kmk.keyboard: coordkeys_pressed={}                                     

⏺ Good news for hardware/firmware: key_number 75 fires correctly and resolves to
  KeyboardKey(code=70) — code 70 (0x46) is exactly the standard HID usage for
  Print Screen. So the matrix, the switch, and KMK are all doing their job
  correctly and sending the right HID report. This is not a hardware fault.

  That pushes the problem downstream, to the Linux input layer or X11/desktop
  environment. Next step: bypass xev entirely and watch the raw kernel input
  event.

  1. Find the Pico's input device:

  cat /proc/bus/input/devices | grep -A5 -i "adafruit\|pico\|kmk"

  Look for a line like Handlers=... eventX — note that eventX number. (If
  nothing matches, run ls /dev/input/by-id/ instead and look for a *-event-kbd
  entry mentioning the Pico.)

  2. Watch raw kernel events:

  sudo evtest /dev/input/eventX

  Press PrtSc and see what happens:

  - If you see a line like EV_KEY / KEY_SYSRQ or EV_KEY / KEY_PRINT reported
  there — the key is reaching the kernel input layer just fine, and the problem
  is X11/your desktop environment eating it before xev's window ever sees it.
  This is extremely common: screenshot utilities (GNOME Screenshot, Flameshot,
  scrot bound via a WM shortcut, etc.) register PrintScreen as a global grab,
  which means X delivers the event only to the grabbing client, never to other
  windows including xev. Worth checking xfce4-keyboard-settings / GNOME Settings
  → Keyboard Shortcuts / your WM config for anything bound to Print Screen, and
  temporarily disabling it to retest in xev.
  - If evtest shows nothing when you press PrtSc, then the HID report genuinely
  isn't reaching the kernel despite KMK sending it — that would be a real
  USB/HID-layer bug worth digging into further (unlikely given the log you
  showed, but let's confirm).

  Can you run that and paste what evtest shows for PrtSc?
✻ Baked for 18s

❯ Let's not solve PrtScr, I am OK for now.                                      
                                                                                
  I pressed F3 5 times, can you reconfirm your theory?                          
                                                                                
  758319 kmk.keyboard: <Event: key_number 22 pressed>: KeyboardKey(code=60)     
  758322 kmk.keyboard: coordkeys_pressed={22: KeyboardKey(code=60)}             
  758324 kmk.keyboard: keys_pressed={KeyboardKey(code=60)}                      
  758380 kmk.keyboard: <Event: key_number 33 pressed>: KeyboardKey(code=78)     
  758383 kmk.keyboard: coordkeys_pressed={22: KeyboardKey(code=60), 33:         
  KeyboardKey(code=78)}                                                         
  758387 kmk.keyboard: keys_pressed={KeyboardKey(code=60),                      
  KeyboardKey(code=78)}                                                         
  758412 kmk.keyboard: <Event: key_number 33 released>: KeyboardKey(code=78)    
  758416 kmk.keyboard: coordkeys_pressed={22: KeyboardKey(code=60)}             
  758418 kmk.keyboard: keys_pressed={KeyboardKey(code=60)}                      
  758422 kmk.keyboard: <Event: key_number 22 released>: KeyboardKey(code=60)    
  758425 kmk.keyboard: coordkeys_pressed={}                                     
  759727 kmk.keyboard: <Event: key_number 22 pressed>: KeyboardKey(code=60)     
  759730 kmk.keyboard: coordkeys_pressed={22: KeyboardKey(code=60)}             
  759733 kmk.keyboard: keys_pressed={KeyboardKey(code=60)}                      
  759739 kmk.keyboard: <Event: key_number 33 pressed>: KeyboardKey(code=78)     
  759742 kmk.keyboard: coordkeys_pressed={22: KeyboardKey(code=60), 33:         
  KeyboardKey(code=78)}                                                         
  759746 kmk.keyboard: keys_pressed={KeyboardKey(code=60),                      
  KeyboardKey(code=78)}                                                         
  759825 kmk.keyboard: <Event: key_number 22 released>: KeyboardKey(code=60)    
  759828 kmk.keyboard: coordkeys_pressed={33: KeyboardKey(code=78)}             
  759831 kmk.keyboard: keys_pressed={KeyboardKey(code=78)}                      
  759836 kmk.keyboard: <Event: key_number 33 released>: KeyboardKey(code=78)    
  759839 kmk.keyboard: coordkeys_pressed={}                                     
  760891 kmk.keyboard: <Event: key_number 22 pressed>: KeyboardKey(code=60)     
  760894 kmk.keyboard: coordkeys_pressed={22: KeyboardKey(code=60)}             
  760897 kmk.keyboard: keys_pressed={KeyboardKey(code=60)}                      
  760919 kmk.keyboard: <Event: key_number 33 pressed>: KeyboardKey(code=78)     
  760922 kmk.keyboard: coordkeys_pressed={22: KeyboardKey(code=60), 33:         
  KeyboardKey(code=78)}                                                         
  760925 kmk.keyboard: keys_pressed={KeyboardKey(code=60),                      
  KeyboardKey(code=78)}                                                         
  760979 kmk.keyboard: <Event: key_number 33 released>: KeyboardKey(code=78)    
  760982 kmk.keyboard: coordkeys_pressed={22: KeyboardKey(code=60)}             
  760985 kmk.keyboard: keys_pressed={KeyboardKey(code=60)}                      
  760990 kmk.keyboard: <Event: key_number 22 released>: KeyboardKey(code=60)    
  760993 kmk.keyboard: coordkeys_pressed={}                                     
  764312 kmk.keyboard: <Event: key_number 22 pressed>: KeyboardKey(code=60)     
  764315 kmk.keyboard: coordkeys_pressed={22: KeyboardKey(code=60)}             
  764318 kmk.keyboard: keys_pressed={KeyboardKey(code=60)}                      
  764415 kmk.keyboard: <Event: key_number 22 released>: KeyboardKey(code=60)    
  764418 kmk.keyboard: coordkeys_pressed={}                                     
  765712 kmk.keyboard: <Event: key_number 22 pressed>: KeyboardKey(code=60)     
  765714 kmk.keyboard: coordkeys_pressed={22: KeyboardKey(code=60)}             
  765717 kmk.keyboard: keys_pressed={KeyboardKey(code=60)}                      
  765761 kmk.keyboard: <Event: key_number 33 pressed>: KeyboardKey(code=78)     
  765764 kmk.keyboard: coordkeys_pressed={22: KeyboardKey(code=60), 33:         
  KeyboardKey(code=78)}                                                         
  765768 kmk.keyboard: keys_pressed={KeyboardKey(code=60),                      
  KeyboardKey(code=78)}                                                         
  765804 kmk.keyboard: <Event: key_number 33 released>: KeyboardKey(code=78)    
  765807 kmk.keyboard: coordkeys_pressed={22: KeyboardKey(code=60)}             
  765810 kmk.keyboard: keys_pressed={KeyboardKey(code=60)}                      
  765814 kmk.keyboard: <Event: key_number 22 released>: KeyboardKey(code=60)    
  765818 kmk.keyboard: coordkeys_pressed={}                                     

⏺ This data is even more conclusive — and refines the theory further.

  ┌───────┬───────────────────┬───────────────┬───────────────┐
  │ Press │ Ghost (33) fired? │ Lag before 33 │ Release order │
  ├───────┼───────────────────┼───────────────┼───────────────┤
  │ 1     │ Yes               │ 61ms          │ 33 then 22    │
  ├───────┼───────────────────┼───────────────┼───────────────┤
  │ 2     │ Yes               │ 12ms          │ 22 then 33    │
  ├───────┼───────────────────┼───────────────┼───────────────┤
  │ 3     │ Yes               │ 28ms          │ 33 then 22    │
  ├───────┼───────────────────┼───────────────┼───────────────┤
  │ 4     │ No                │ —             │ —             │
  ├───────┼───────────────────┼───────────────┼───────────────┤
  │ 5     │ Yes               │ 49ms          │ 33 then 22    │
  └───────┴───────────────────┴───────────────┴───────────────┘

  Press 4 produced zero ghosting — a clean, single key_number 22 event with no
  33 at all. That's the key new fact: it rules out a fixed short (a solder
  bridge or permanent wire-to-wire short would fire every single time, with
  roughly consistent timing). Instead you're getting the ghost ~80% of the time,
  with lag ranging from 12ms to 61ms and no consistent release order.

  This is exactly what you'd expect from a marginal, pressure-dependent 
  mechanical contact rather than an electrical fault: something in the
  keyboard's physical construction (most likely a worn/cracked conductive trace
  on the membrane, or debris/contamination between the F3 and Next pads) that
  only bridges the two contacts when the key is pressed hard enough, fast
  enough, or at the right angle — and sometimes doesn't bridge at all. That
  fully explains the variable lag and the one clean press.

  So: confirmed hardware, and now narrowed from "short somewhere in the row
  wiring" to "intermittent, force/angle-sensitive contact fault localized to the
  physical keys in that F-key column, most likely on the membrane itself" —
  worth opening the keyboard and inspecting/cleaning that column's membrane
  contacts if you want to pursue a repair.

✻ Crunched for 17s

❯ /export                                                                       
  ⎿  Conversation exported to: /Users/alex/code/toshiba-t1200xe-keyboard/2026-07-
     09-231242-ghost-keys-problem.txt

❯ Just theoretically - why this is not affecting F1, F2, F4, F6, F10, F11, F12? 
  Any pattern you can recognize?                                                

⏺ Good question — the fact that it's not random, but confined to a contiguous
  block, is itself informative.

  Look at where rows 0/1 sit versus rows 2-7 in the matrix (code.py:49-58):

  row0: F1,  F2    ← unaffected
  row1: F11, F12   ← unaffected
  row2: F3,  F4    ← affected (col0 confirmed)
  row3: PGDN,PGUP  ← affected (col0 confirmed)
  row4: F5,  F6    ← affected (col0 confirmed)
  row5: F7,  F8    ← affected (col0 AND col1 confirmed)
  row6: F9,  F10   ← affected (col0 confirmed; col1 only as receiver)
  row7: END, LALT  ← affected (col0 confirmed, as receiver only)

  Rows 2 through 7 form one unbroken block; rows 0-1 are cleanly excluded. If
  this were per-key wear (dome fatigue, dirty individual contacts), you'd expect
  it to correlate with usage frequency — but F4, F6, F12 are lightly used keys,
  while heavily-used keys elsewhere (Enter, Shift, Space) show nothing.
  Usage-based wear doesn't explain a clean contiguous cutoff at row 2.

  A contiguous block pointing at rows, not individual keys, is more consistent
  with the fault living in a shared row conductor, not in the switches
  themselves. If a physical crack, corrosion patch, or marginal connector
  segment exists at one location on the keyboard's PCB/ribbon — say, wherever
  the traces for rows 2-7 happen to run together or pass through a shared
  connector segment — it would affect every key on those rows, while rows 0-1,
  routed through an intact/different segment, stay clean. That also fits the
  intermittent, force-dependent timing you saw: a compromised trace bridging to
  its neighbor only when flexed by a keypress, rather than a permanent short.

  This generates a testable prediction: if the fault is on the shared row line 
  (not specific to the F-key switches), other keys on the same rows should ghost
  too — e.g. pressing TAB (row2, col2) should show key_number for TAB and Q
  (row3, col2) in the debug log, even though you haven't touched those keys yet.
  That would confirm the defect is row-wide, not F-key-column-specific, and
  would also explain why you haven't noticed it elsewhere — you may simply not
  have been watching for it outside the F-key strip. Worth a quick test if you
  want to nail this down further.

✻ Cooked for 1m 3s

※ recap: We're debugging your Toshiba keyboard's double-key and PrtSc issues; F3 and PrtSc are confirmed hardware, not firmware. Next: press TAB and check the debug log to see if row 2/3 ghost too. (disable recaps in /config)

❯ oddly enough, Tab works well very stablely                                    

⏺ That's the deciding data point — it kills the "whole row conductor is shorted"
  theory. If row 2's actual GPIO/wire were compromised, TAB (row2, col2) would
  ghost into Q (row3, col2) just as reliably as F3 ghosts into Next. It doesn't.
  So the row-2 line itself is electrically fine; the fault has to be specific
  to columns 0/1 at that row junction, not the row as a whole.

  That points at the physical layout of this specific keyboard rather than
  generic wiring: the T1200XE's F-keys form a separate, narrow 2-column × 8-row
  strip on the far left, distinct from the main QWERTY block. In that strip, the
  row conductors for rows 2 through 7 have to be packed tightly together in a
  small physical space to serve just those two columns — whereas the same row
  wires, once they fan out to reach col2 (TAB) and beyond into the main matrix,
  are spread much further apart. A localized defect (a crease, crack in
  conductive ink, corrosion, contamination) sitting specifically in that cramped
  strip could bridge adjacent row conductors right there, while the very same
  wires are far enough apart everywhere else on the board that the identical
  defect never manifests once you're at col2+.

  That's consistent with everything so far:
  - Only col0/col1 affected → defect is physically located in the narrow F-key
  strip, not on the row wire generally.
  - Confined to rows 2-7, not 0-1 → whatever crease/damage exists sits at a
  specific spot in that strip, probably lower down, not right at the top.
  - Intermittent, force-dependent timing → a marginal mechanical bridge, not a
  hard short.

  One more test would nail it down further: press F4 (row2, col1) — if it ghosts
  into PgUp (row3, col1) the same way F3 ghosts into Next, that confirms the
  defect spans both columns of the strip at that row junction, not just col0.
  That would strongly point at a physical fault inside the F-key strip's flex
  circuit itself as the repair target.

✻ Churned for 37s

❯ before I do F4, here is a new finding. F12 sometimes leads to F12 + F11       
                                                                                
  286361 kmk.keyboard: <Event: key_number 12 pressed>: KeyboardKey(code=69)     
  286364 kmk.keyboard: coordkeys_pressed={12: KeyboardKey(code=69)}             
  286367 kmk.keyboard: keys_pressed={KeyboardKey(code=69)}                      
  286400 kmk.keyboard: <Event: key_number 11 pressed>: KeyboardKey(code=68)     
  286403 kmk.keyboard: coordkeys_pressed={12: KeyboardKey(code=69), 11:         
  KeyboardKey(code=68)}                                                         
  286407 kmk.keyboard: keys_pressed={KeyboardKey(code=69),                      
  KeyboardKey(code=68)}                                                         
  286442 kmk.keyboard: <Event: key_number 11 released>: KeyboardKey(code=68)    
  286445 kmk.keyboard: coordkeys_pressed={12: KeyboardKey(code=69)}             
  286448 kmk.keyboard: keys_pressed={KeyboardKey(code=69)}                      
  286453 kmk.keyboard: <Event: key_number 12 released>: KeyboardKey(code=69)    
  286456 kmk.keyboard: coordkeys_pressed={}                                     
  286542 kmk.keyboard: <Event: key_number 12 pressed>: KeyboardKey(code=69)     
  286545 kmk.keyboard: coordkeys_pressed={12: KeyboardKey(code=69)}             
  286547 kmk.keyboard: keys_pressed={KeyboardKey(code=69)}                      
  286634 kmk.keyboard: <Event: key_number 12 released>: KeyboardKey(code=69)    
  286637 kmk.keyboard: coordkeys_pressed={}                                     
  286730 kmk.keyboard: <Event: key_number 12 pressed>: KeyboardKey(code=69)     
  286733 kmk.keyboard: coordkeys_pressed={12: KeyboardKey(code=69)}             
  286736 kmk.keyboard: keys_pressed={KeyboardKey(code=69)}                      
  286828 kmk.keyboard: <Event: key_number 12 released>: KeyboardKey(code=69)    
  286831 kmk.keyboard: coordkeys_pressed={}                                     
  287723 kmk.keyboard: <Event: key_number 12 pressed>: KeyboardKey(code=69)     
  287726 kmk.keyboard: coordkeys_pressed={12: KeyboardKey(code=69)}             
  287729 kmk.keyboard: keys_pressed={KeyboardKey(code=69)}                      
  287802 kmk.keyboard: <Event: key_number 12 released>: KeyboardKey(code=69)    
  287805 kmk.keyboard: coordkeys_pressed={}                                     
  288174 kmk.keyboard: <Event: key_number 12 pressed>: KeyboardKey(code=69)     
  288177 kmk.keyboard: coordkeys_pressed={12: KeyboardKey(code=69)}             
  288180 kmk.keyboard: keys_pressed={KeyboardKey(code=69)}                      
  288260 kmk.keyboard: <Event: key_number 12 released>: KeyboardKey(code=69)    
  288263 kmk.keyboard: coordkeys_pressed={}                                     
  288698 kmk.keyboard: <Event: key_number 12 pressed>: KeyboardKey(code=69)     
  288701 kmk.keyboard: coordkeys_pressed={12: KeyboardKey(code=69)}             
  288704 kmk.keyboard: keys_pressed={KeyboardKey(code=69)}                      
  288770 kmk.keyboard: <Event: key_number 12 released>: KeyboardKey(code=69)    
  288773 kmk.keyboard: coordkeys_pressed={}                                     
  288869 kmk.keyboard: <Event: key_number 12 pressed>: KeyboardKey(code=69)     
  288872 kmk.keyboard: coordkeys_pressed={12: KeyboardKey(code=69)}             
  288875 kmk.keyboard: keys_pressed={KeyboardKey(code=69)}                      
  288914 kmk.keyboard: <Event: key_number 11 pressed>: KeyboardKey(code=68)     
  288917 kmk.keyboard: coordkeys_pressed={12: KeyboardKey(code=69), 11:         
  KeyboardKey(code=68)}                                                         
  288921 kmk.keyboard: keys_pressed={KeyboardKey(code=69),                      
  KeyboardKey(code=68)}                                                         
  288954 kmk.keyboard: <Event: key_number 11 released>: KeyboardKey(code=68)    
  288957 kmk.keyboard: coordkeys_pressed={12: KeyboardKey(code=69)}             
  288960 kmk.keyboard: keys_pressed={KeyboardKey(code=69)}                      
  288964 kmk.keyboard: <Event: key_number 12 released>: KeyboardKey(code=69)    
  288967 kmk.keyboard: coordkeys_pressed={}                                     

⏺ This is an important new data point — it changes the shape of the theory. F12
  (row1, col1) occasionally ghosting into F11 (row1, col0) is a column-adjacent
  leak (same row, neighboring column), whereas everything before was a
  row-adjacent leak (same column, neighboring row). That's a different axis
  entirely, and it falsifies "rows 0-1 are clean" — row 1 is affected too, just
  via its horizontal neighbor rather than the row below it (which would've been
  F3, and you haven't seen F11↔F3 crosstalk reported).

  Same intermittency signature as before: out of 7 presses, only 2 ghosted
  (~29%), with lag (39ms, 45ms) and inconsistent release order (11-then-12 both
  times, but 12 always led on press) — same soft/marginal-contact fingerprint as
  F3→Next.

  This pushes the theory one level more general: it's not a single localized
  row-to-row trace defect. It looks like the entire F-key strip's contact layer 
  is marginal, and any physically neighboring pair of switches in that tightly
  packed 2-column × 8-row block — whether stacked vertically (F3/Next) or
  side-by-side horizontally (F11/F12) — can occasionally cross-trigger under a
  firm press. That's consistent with generalized wear, aging, or contamination
  across that whole block (a common failure mode for a 35+ year old membrane),
  rather than one crack at one spot. It also fits why TAB is rock solid: TAB
  isn't part of that cramped F-key strip — it's a normally-spaced key in the
  main matrix with presumably better-preserved isolation.

  Given this, when you test F4, it's worth checking both of its neighbors, not
  just PgUp below it:
  - F4 → PgUp (row-neighbor, same axis as your original F3 test)
  - F4 → F3 (column-neighbor, same axis as F12→F11)

  If both show up intermittently, that would confirm the fault is strip-wide
  rather than tied to one direction, and would point squarely at
  replacing/cleaning/repairing that whole F-key strip module as the fix, rather
  than chasing one wire or trace.

✻ Cogitated for 43s

❯ F4 does not work either as it turns out (not sure if I have the full log)     
                                                                                
  394180 kmk.keyboard: keys_pressed={KeyboardKey(code=61)}                      
  394186 kmk.keyboard: <Event: key_number 22 pressed>: KeyboardKey(code=60)     
  394189 kmk.keyboard: coordkeys_pressed={22: KeyboardKey(code=60), 23:         
  KeyboardKey(code=61)}                                                         
  394193 kmk.keyboard: keys_pressed={KeyboardKey(code=61),                      
  KeyboardKey(code=60)}                                                         
  394438 kmk.keyboard: <Event: key_number 22 released>: KeyboardKey(code=60)    
  394442 kmk.keyboard: coordkeys_pressed={23: KeyboardKey(code=61)}             
  394445 kmk.keyboard: keys_pressed={KeyboardKey(code=61)}                      
  394449 kmk.keyboard: <Event: key_number 23 released>: KeyboardKey(code=61)    
  394453 kmk.keyboard: coordkeys_pressed={}                                     
  394958 kmk.keyboard: <Event: key_number 23 pressed>: KeyboardKey(code=61)     
  394961 kmk.keyboard: coordkeys_pressed={23: KeyboardKey(code=61)}             
  394963 kmk.keyboard: keys_pressed={KeyboardKey(code=61)}                      
  394976 kmk.keyboard: <Event: key_number 22 pressed>: KeyboardKey(code=60)     
  394979 kmk.keyboard: coordkeys_pressed={22: KeyboardKey(code=60), 23:         
  KeyboardKey(code=61)}                                                         
  394983 kmk.keyboard: keys_pressed={KeyboardKey(code=61),                      
  KeyboardKey(code=60)}                                                         
  395274 kmk.keyboard: <Event: key_number 22 released>: KeyboardKey(code=60)    
  395277 kmk.keyboard: coordkeys_pressed={23: KeyboardKey(code=61)}             
  395280 kmk.keyboard: keys_pressed={KeyboardKey(code=61)}                      
  395285 kmk.keyboard: <Event: key_number 23 released>: KeyboardKey(code=61)    
  395288 kmk.keyboard: coordkeys_pressed={}                                     
  395690 kmk.keyboard: <Event: key_number 23 pressed>: KeyboardKey(code=61)     
  395693 kmk.keyboard: coordkeys_pressed={23: KeyboardKey(code=61)}             
  395696 kmk.keyboard: keys_pressed={KeyboardKey(code=61)}                      
  395702 kmk.keyboard: <Event: key_number 22 pressed>: KeyboardKey(code=60)     
  395705 kmk.keyboard: coordkeys_pressed={22: KeyboardKey(code=60), 23:         
  KeyboardKey(code=61)}                                                         
  395708 kmk.keyboard: keys_pressed={KeyboardKey(code=61),                      
  KeyboardKey(code=60)}                                                         
  396054 kmk.keyboard: <Event: key_number 22 released>: KeyboardKey(code=60)    
  396057 kmk.keyboard: coordkeys_pressed={23: KeyboardKey(code=61)}             
  396060 kmk.keyboard: keys_pressed={KeyboardKey(code=61)}                      
  396065 kmk.keyboard: <Event: key_number 23 released>: KeyboardKey(code=61)    
  396068 kmk.keyboard: coordkeys_pressed={}                                     
  396706 kmk.keyboard: <Event: key_number 23 pressed>: KeyboardKey(code=61)     
  396709 kmk.keyboard: coordkeys_pressed={23: KeyboardKey(code=61)}             
  396712 kmk.keyboard: keys_pressed={KeyboardKey(code=61)}                      
  396730 kmk.keyboard: <Event: key_number 22 pressed>: KeyboardKey(code=60)     
  396733 kmk.keyboard: coordkeys_pressed={22: KeyboardKey(code=60), 23:         
  KeyboardKey(code=61)}                                                         
  396737 kmk.keyboard: keys_pressed={KeyboardKey(code=61),                      
  KeyboardKey(code=60)}                                                         
  397225 kmk.keyboard: <Event: key_number 22 released>: KeyboardKey(code=60)    
  397229 kmk.keyboard: coordkeys_pressed={23: KeyboardKey(code=61)}             
  397231 kmk.keyboard: keys_pressed={KeyboardKey(code=61)}                      
  397236 kmk.keyboard: <Event: key_number 23 released>: KeyboardKey(code=61)    
  397239 kmk.keyboard: coordkeys_pressed={}                                     
  417836 kmk.keyboard: <Event: key_number 23 pressed>: KeyboardKey(code=61)     
  417839 kmk.keyboard: coordkeys_pressed={23: KeyboardKey(code=61)}             
  417841 kmk.keyboard: keys_pressed={KeyboardKey(code=61)}                      
  417847 kmk.keyboard: <Event: key_number 22 pressed>: KeyboardKey(code=60)     
  417850 kmk.keyboard: coordkeys_pressed={22: KeyboardKey(code=60), 23:         
  KeyboardKey(code=61)}                                                         
  417854 kmk.keyboard: keys_pressed={KeyboardKey(code=61),                      
  KeyboardKey(code=60)}                                                         
  417988 kmk.keyboard: <Event: key_number 22 released>: KeyboardKey(code=60)    
  417991 kmk.keyboard: coordkeys_pressed={23: KeyboardKey(code=61)}             
  417993 kmk.keyboard: keys_pressed={KeyboardKey(code=61)}                      
  417998 kmk.keyboard: <Event: key_number 23 released>: KeyboardKey(code=61)    
  418001 kmk.keyboard: coordkeys_pressed={}                                     

⏺ key_number 23 = row2,col1 = F4 (code 61), key_number 22 = row2,col0 = F3 (code
  60). This is the clearest signal yet — and it's a stronger fault than
  anything seen before:

  - F4 → F3 fires on every single press shown (6/6), not intermittently like
  F3→Next (~80%) or F12→F11 (~29%).
  - The lag is short and very consistent: 14–18ms every time (vs. 12–61ms
  variable lag elsewhere).
  - The order is also rock-consistent: F4 presses first, F3 follows ~15ms later,
  then F3 releases first and F4 releases ~11ms after — same nesting pattern
  every time.

  That consistency (vs. everything else being intermittent/variable) suggests
  this particular junction — col1↔col0 at row2 — has degraded further than the
  others, more like an established short than a marginal, force-dependent
  contact. Combined with the F12→F11 result, you now have crosstalk confirmed on
  both axes of the F-key strip: row-adjacent (F3→Next, F5→F7, etc.) and
  column-adjacent (F12→F11, F4→F3). That reinforces the "whole strip is
  degrading" theory over a single localized defect.

  One asymmetry worth noting: in every log so far, the ghost only ever runs one 
  direction — F4 produces F3, never the reverse (F3 alone only ever produced
  Next, not F4). Same with F12→F11: never observed F11 alone producing F12. That
  directionality is a useful clue: a simple resistive short between two column
  traces should leak both ways equally. A one-way leak is more consistent with
  something like a corrosion filament/tin whisker bridging from one pad toward
  its neighbor (which can be physically asymmetric), or a mechanical/membrane
  deformation that only pushes toward one side when that specific key is
  pressed.

  Worth double-checking: press F3 several times in a row (you've only sampled it
  a handful of times) and see if F4 ever shows up as a ghost — if it's truly
  one-directional even over many tries, that's a strong hint the physical defect
  has a specific orientation, which would matter if you end up opening the
  keyboard to inspect/repair that area.

✻ Brewed for 56s

❯ the keyboard has diodes for each key, can this explain uni-directionality?    
  could it be a faulty diode?                                                   

⏺ Good instinct to check, but the per-key diode is probably not the mechanism
  here — the topology doesn't quite support it.

  Each key's diode sits in series with its own mechanical switch contact. For F3
  (row2, col0), current only flows through F3's diode if F3's own switch is
  physically closed. Row2 being driven HIGH (which happens every scan cycle,
  whether or not F4 is pressed) forward-biases every diode in that row — but a
  forward-biased diode with an open switch in series still blocks current. So
  even a completely dead-shorted F3 diode wouldn't explain col0 going HIGH only
  when F4 is pressed and F3 is untouched — a shorted F3 diode would instead make
  F3 register on every single row2 scan, constantly, regardless of F4, since
  row2 gets driven HIGH continuously during normal scanning. That's not what
  you're seeing (F3 behaves normally except when F4 happens to trigger it).

  Similarly, a leaky/reverse-conducting F4 diode would only let current bleed
  backward from col1 into row2 — it doesn't create a path from col1 to col0,
  since those are two separate column wires with no diode connecting them to
  each other.

  For col0 to go HIGH purely because col1 went HIGH, you need a direct
  electrical path between the col0 and col1 traces themselves, bypassing both
  switches and both diodes — i.e., a physical bridge on the PCB/membrane
  specifically near row2 (and separately near row1 for F11/F12). That fits
  everything you've measured: it's row-specific (only where the bridge
  physically exists), independent of the keys' own diodes, and explains why F3
  alone doesn't misfire on every scan.

  The one-directionality is still explainable without invoking a broken
  intentional diode: corrosion or oxide bridges between two copper traces/pads
  don't always behave like a clean resistor — oxide layers between two metal
  surfaces can form an accidental rectifying junction (sometimes called the
  "rusty bolt effect"), conducting much better in one direction than the other.
  A stray solder whisker or conductive debris flake anchored on the col1 side,
  flexing onto the col0 pad only when that specific key is pressed, would
  produce the same asymmetric result mechanically, no oxide chemistry required.

  If you want to test this directly: use your multimeter's diode-test mode (not
  just continuity) between the col0 and col1 traces near row2, in both
  polarities. If you get a low reading one way and open/very-high the other way,
  that's a real rectifying bridge between the columns — strong confirmation of
  an unintended short/corrosion junction rather than a failed keyboard diode.

✻ Crunched for 1m 6s

※ recap: We're diagnosing intermittent ghost keys on the Toshiba T1200XE keyboard via KMK debug logs. Confirmed a physical fault in the F-key strip affecting F3, F4, F5, F7, F8, F9, F11, F12. Next: test F3 multiple times to check if F4 ever ghosts back (reverse direction).

❯ can you write a diagnostic code that would ask me to start pressing a certain 
  key and would just keep going while the key is producing the expected code,   
  but report an error when ghost keys are detected. I want to have more         
  convenient way to test this via hundres of key strokes. It should just print  
  the ghost keys sequence and switch to the next key. I will be just quickly    
  pressing whatever key I am asked to press. It's OK if that code would not use 
  KMK. BUt I want to use serial comms for it.                                   

  Searched for 2 patterns, read 1 file (ctrl+o to expand)

⏺ Write(diagnostics/ghost_key_test.py)
  ⎿  Wrote 134 lines to diagnostics/ghost_key_test.py
       2 Ghost-key diagnostic for the Toshiba T1200XE matrix.
       3 
         K entirely, so to CircuitPython's keypad.KeyMatrix, bypassing KM
       5 the raw electrical behavior of the matrix can be tested without 
         any HID/OS
         e serialent. Nothing gets typed anywhere - results only go to th
       7 console.
       9 Usage:
      10   1. Back up the real CIRCUITPY/code.py, then copy this file ove
         r it.
     … +148 lines (ctrl+o to expand)

⏺ Created diagnostics/ghost_key_test.py. It's standalone — talks directly to
  CircuitPython's keypad.KeyMatrix, no KMK, no HID output, so nothing gets typed
  anywhere; it only prints to the serial console.

  How it works:
  - Walks through the F-key strip (all 16 keys in cols 0/1, rows 0-7 — the same
  set you've been probing) in order.
  - For each key, prints a prompt and then just counts your presses silently.
  - If any other key_number fires while the target key is held down, that's a
  ghost: it prints something like !! GHOST on press #12: also saw [PGDN] and
  immediately moves to the next key — no point burning more presses on a key
  already caught.
  - If a key survives 100 clean presses with no ghost, it prints PASSED and
  moves on — this is where "hundreds of keystrokes" actually matters, to build
  confidence on keys that seem clean.
  - Ctrl+C aborts early and still prints the summary table of everything tested
  so far.
  - Edit TEST_SEQUENCE (or PRESSES_PER_KEY) at the top if you want to test other
  keys or change the threshold.

  To use it: back up your current code.py, copy diagnostics/ghost_key_test.py
  over CIRCUITPY/code.py, open the serial console, and press Ctrl+D to run it.
  When you're done, restore the original code.py.

✻ Crunched for 2m 35s

※ recap: We're diagnosing ghost keys and a dead PrtSc on your Toshiba keyboard firmware. I just built a serial-based diagnostic script; next step is to copy it to CIRCUITPY as code.py and run it to test all the F-strip keys.

❯ Are you sure diagnostics code works? It did not report ghosting on F7, but    
  with KMK I still see a ghost:                                                 
                                                                                
  962417 kmk.keyboard: <Event: key_number 55 pressed>: KeyboardKey(code=64)     
  962420 kmk.keyboard: coordkeys_pressed={55: KeyboardKey(code=64)}             
  962422 kmk.keyboard: keys_pressed={KeyboardKey(code=64)}                      
  962427 kmk.keyboard: <Event: key_number 66 pressed>: KeyboardKey(code=66)     
  962431 kmk.keyboard: coordkeys_pressed={66: KeyboardKey(code=66), 55:         
  KeyboardKey(code=64)}                                                         
  962435 kmk.keyboard: keys_pressed={KeyboardKey(code=64),                      
  KeyboardKey(code=66)}                                                         
  962463 kmk.keyboard: <Event: key_number 66 released>: KeyboardKey(code=66)    
  962465 kmk.keyboard: coordkeys_pressed={55: KeyboardKey(code=64)}             
  962468 kmk.keyboard: keys_pressed={KeyboardKey(code=64)}                      
  962490 kmk.keyboard: <Event: key_number 55 released>: KeyboardKey(code=64)    
  962493 kmk.keyboard: coordkeys_pressed={}                                     
  962599 kmk.keyboard: <Event: key_number 55 pressed>: KeyboardKey(code=64)     
  962602 kmk.keyboard: coordkeys_pressed={55: KeyboardKey(code=64)}             
  962604 kmk.keyboard: keys_pressed={KeyboardKey(code=64)}                      
  962686 kmk.keyboard: <Event: key_number 55 released>: KeyboardKey(code=64)    
  962690 kmk.keyboard: coordkeys_pressed={}                                     
  963156 kmk.keyboard: <Event: key_number 55 pressed>: KeyboardKey(code=64)     
  963160 kmk.keyboard: coordkeys_pressed={55: KeyboardKey(code=64)}             
  963162 kmk.keyboard: keys_pressed={KeyboardKey(code=64)}                      
  963168 kmk.keyboard: <Event: key_number 66 pressed>: KeyboardKey(code=66)     
  963171 kmk.keyboard: coordkeys_pressed={66: KeyboardKey(code=66), 55:         
  KeyboardKey(code=64)}                                                         
  963173 kmk.keyboard: keys_pressed={KeyboardKey(code=64),                      
  KeyboardKey(code=66)}                                                         
  963222 kmk.keyboard: <Event: key_number 66 released>: KeyboardKey(code=66)    
  963225 kmk.keyboard: coordkeys_pressed={55: KeyboardKey(code=64)}             
  963228 kmk.keyboard: keys_pressed={KeyboardKey(code=64)}                      
  963246 kmk.keyboard: <Event: key_number 55 released>: KeyboardKey(code=64)    
  963249 kmk.keyboard: coordkeys_pressed={}                                     
  963454 kmk.keyboard: <Event: key_number 55 pressed>: KeyboardKey(code=64)     
  963457 kmk.keyboard: coordkeys_pressed={55: KeyboardKey(code=64)}             
  963459 kmk.keyboard: keys_pressed={KeyboardKey(code=64)}                      
  963533 kmk.keyboard: <Event: key_number 55 released>: KeyboardKey(code=64)    
  963536 kmk.keyboard: coordkeys_pressed={}                                     
  963660 kmk.keyboard: <Event: key_number 55 pressed>: KeyboardKey(code=64)     
  963664 kmk.keyboard: coordkeys_pressed={55: KeyboardKey(code=64)}             
  963666 kmk.keyboard: keys_pressed={KeyboardKey(code=64)}                      
  963742 kmk.keyboard: <Event: key_number 55 released>: KeyboardKey(code=64)    
  963745 kmk.keyboard: coordkeys_pressed={}                                     
  963887 kmk.keyboard: <Event: key_number 55 pressed>: KeyboardKey(code=64)     
  963891 kmk.keyboard: coordkeys_pressed={55: KeyboardKey(code=64)}             
  963893 kmk.keyboard: keys_pressed={KeyboardKey(code=64)}                      
  963975 kmk.keyboard: <Event: key_number 55 released>: KeyboardKey(code=64)    
⏺ Before assuming a real bug, let's check the likely mundane cause:
  TEST_SEQUENCE walks the whole F-key strip in order — F1, F2, F11, F12, F3, F4,
  PgDn, PgUp, F5, F6, then F7. Each key needs up to 100 clean presses before it
  auto-advances. That means reaching F7 at all requires working through ~9 keys
  before it, each potentially demanding up to 100 presses — could be 500+
  keystrokes just to get there. It's very possible you didn't actually get far
  enough for F7 to accumulate enough attempts to catch its ghost (which, per the
  KMK log you just showed, fires roughly 2 out of 5 times — not every press),
  or you Ctrl+C'd out of it partway through the earlier keys before F7 ever got
  tested.

  Quick question so I know what actually happened: did the script explicitly
  print F7 PASSED: 100 clean presses, no ghosts., or did you stop it before it
  finished that key?

  Either way, testing the whole strip sequentially every time is impractical for
  spot-checks. Let me make it easy to test just one key.

  Read 1 file (ctrl+o to expand)

⏺ Update(diagnostics/ghost_key_test.py)
  ⎿  Added 15 lines, removed 8 lines
      57      return 'UNKNOWN(%d)' % number
      58  
      59  
      60 -# Keys to walk through, in order. Defaults to the whole F-key s
         -trip (cols 0-1,                                                
      61 -# every row) since that's where the ghosting has shown up so fa
         -r. Edit freely                                                 
      62 -# to test other keys - e.g. add key_number(2, 2) to test TAB.  
      63 -TEST_SEQUENCE = [                                              
      64 -    key_number(row, col)                                       
      65 -    for row in range(8)                                        
      66 -    for col in (0, 1)                                          
      67 -]                                                              
      60 +NAME_TO_NUMBER = {name: n for n, name in enumerate(LABELS) if n
         +ame != '--'}                                                   
      61  
      62 +# To re-test just one or two keys instead of walking the whole 
         +strip, list                                                    
      63 +# their names here, e.g. ONLY_TEST = ['F7']. Leave empty to tes
         +t the whole                                                    
      64 +# F-key strip (cols 0-1, every row) in order.                  
      65 +ONLY_TEST = []                                                 
      66 +                                                               
      67 +if ONLY_TEST:                                                  
      68 +    TEST_SEQUENCE = [NAME_TO_NUMBER[name] for name in ONLY_TEST
         +]                                                              
      69 +else:                                                          
      70 +    TEST_SEQUENCE = [                                          
      71 +        key_number(row, col)                                   
      72 +        for row in range(8)                                    
      73 +        for col in (0, 1)                                      
      74 +    ]                                                          
      75 +                                                               
      76  PRESSES_PER_KEY = 100  # clean presses needed to pass a key wit
          h no ghost seen
      77  
      78  matrix = keypad.KeyMatrix(

⏺ To re-test just F7 quickly, edit the copied file's ONLY_TEST = [] to ONLY_TEST
  = ['F7'] and re-run — it'll skip straight to F7 and give you the full
  100-press window without having to first grind through F1–F6.

  Give that a try and let me know whether it now catches the ghost, and whether
  the original full-strip run actually reached and finished F7 or not — that'll
  tell us if this was just the sequencing issue or something deeper in the
  detection logic.

✻ Churned for 1m 34s

※ recap: We're diagnosing your Toshiba keyboard's ghosting and dead PrtSc via serial debug logs. I added a way to re-test just F7 alone in the diagnostic script; next step is running that and seeing if it now catches the ghost.

❯ Ghost-key diagnostic - 1 keys to test.                                        
                                                                                
  === Press F7 repeatedly (up to 100 times) ===                                 
      (moves on automatically once a ghost is seen, or the target is reached)   
    !! GHOST on press #1: also saw [F9]                                         
                                                                                
  === Summary ===                                                               
    F7     GHOSTED                                                              

⏺ That confirms it — the script does work correctly; it just needed the targeted
  ONLY_TEST run to reach F7 within a reasonable number of presses. Ghost caught
  immediately on press #1: F7 → F7 + F9, matching what you saw in the KMK log.

  So the earlier full-strip run wasn't a false negative in the detection logic —
  it's almost certainly that F7 never got enough (or any) presses before you
  stopped or moved past it, since it's queued behind 9 other keys each wanting
  up to 100 clean presses. Good to know the tool is trustworthy; from here it's
  probably more efficient to always drive it via ONLY_TEST for whichever key(s)
  you're actively investigating, rather than the full sequential walk.

✻ Baked for 4s

❯ can you use this scan of keyboard PBC to locate the reason or provide me with 
  instructions how to locate the reason of cross talking of F7 and F9?          
                                                                                
  [Image #5]                                                                    
  ⎿  [Image #5]

⏺ I can see the board, but I have to be upfront about the limits of what a
  top-down photo like this can actually tell us: this is the solder side of a
  rigid PCB, and the fault we've isolated (a short between the row5 and row6
  nets, specifically at col0) is very likely a hairline trace crack, a
  microscopic solder bridge, or a corrosion film — none of which reliably show
  up at this resolution/angle, even at 100% zoom. I don't want to point you at a
  spot on the board with false confidence when the actual defect could easily
  be invisible in this shot or physically somewhere else along those two traces.

  What I can see: it's a genuine keyswitch PCB (not a flex membrane) with
  individually-soldered diodes scattered across the board — those small black
  rectangular components mixed in among the solder joints are almost certainly
  your per-key diodes, one per switch, which matches the README's "diode on
  every key." There's a Sumitomo FFC ribbon exiting bottom-right (this is
  presumably the connector now wired to your Pico), and a partial part/FRU
  number silkscreened near the middle-left (looks like it starts ...AAA1309 —
  worth reading in person and searching for a Toshiba service manual; if one
  exists with a matrix schematic, it would save you from having to
  reverse-engineer trace routing by eye).

  Here's the procedure I'd actually trust to locate the fault:

  1. Confirm which physical pins are row5/row6 at the connector.
  Since the crosstalk is row5↔row6 (F7=row5,col0; F9=row6,col0 — same axis as
  your original F3→Next finding, not the column-axis F4→F3 one), the two nets
  you care about are whatever pins on the FFC carry GP15 (row5) and GP22 (row6)
  back to the Pico. Check your wiring notes/photos of the Pico end to map "which
  FFC conductor = row5" and "which = row6."

  2. Multimeter diode-test between those two pins at the connector, board
  unpowered, no keys pressed. You already ruled out GP13↔GP14 (row2/row3) this
  way — repeat it for row5/row6. A short here (in either polarity) means the
  fault sits somewhere between the connector and wherever the two traces diverge
  on the board — not necessarily right under the F7/F9 keycaps.

  3. If that's open/clean at rest, test under mechanical stress, since we
  established this is a force/flex-dependent intermittent contact, not a hard
  short: probe row5↔row6 continuity again while pressing F7 down, and while
  gently flexing the board near the F7/F9 area.

  4. Visually trace the row5 and row6 copper traces from the connector across
  the board (a raking light and a loupe/magnifier help a lot here — regular room
  light tends to hide hairline cracks). Look specifically for where the two
  traces run parallel and close together — that's the only place a bridge/crack
  could actually cause this. They may run close together in more than one spot,
  not just near F7/F9.

  5. At each close-proximity point, inspect for: a stray solder ball or whisker
  bridging the two traces, a greenish/dark corrosion spot between adjacent pads
  or vias, or a trace with a visible nick/scratch through the solder mask.

  6. If you find a suspect spot, a cotton swab with isopropyl alcohol to clean
  corrosion, or a careful reflow with a fine-tip iron on a cracked/cold joint,
  is a reasonable first repair attempt — then re-run the ONLY_TEST = ['F7']
  diagnostic to confirm.

  If you can get a clear photo of the component (top) side — where the
  silkscreen reference designators for the diodes/switches usually live — and
  can identify the F7/F9 switch positions on it, I can help correlate that with
  the row5/row6 trace path more precisely than I can from this solder-side shot
  alone.

✻ Baked for 1m 29s

❯ addition - the keys are numbered as this: F7 - 118, F9 - 120                  

⏺ Bash(sips -g pixelWidth -g pixelHeight "/Users/alex/.claude/image-cache/2640f5
      89-9b9e-41d5-b1f0-3f4ec921f0c6/5.png")
  ⎿  /Users/alex/.claude/image-cache/2640f589-9b9e-41d5-b1f0-3f4ec921f0c6/5
     .png
       pixelWidth: 1545
       pixelHeight: 2000

⏺ Bash(mkdir -p /private/tmp/claude-501/-Users-alex-code-toshiba-t1200xe-keyboar
      d/2640f589-9b9e-41d5-b1f0-3f4ec921f0c6/scratchpad
      sips -c 500 500 -Z 1000 "/Users/alex/…)
  ⎿  /Users/alex/.claude/image-cache/2640f589-9b9e-41d5-b1f0-3f4ec921f0c6/5
     .png
       /private/tmp/claude-501/-Users-alex-code-toshiba-t1200xe-keyboard/26
     … +5 lines (ctrl+o to expand)

❯ I marked both keys with blue tape - can you see that?                         

⏺ Bash(which convert magick python3 2>&1; python3 -c "import PIL; print('PIL
      ok')" 2>&1)
  ⎿  Error: Exit code 1
     convert not found
     magick not found
     /opt/homebrew/bin/python3
     Traceback (most recent call last):
       File "<string>", line 1, in <module>
         import PIL; print('PIL ok')
         ^^^^^^^^^^
     ModuleNotFoundError: No module named 'PIL'

⏺ Bash(sips --help 2>&1 | grep -i -A2 "crop")
  ⎿      -c, --cropToHeightWidth pixelsH pixelsW
             --cropOffset offsetY offsetH
         -p, --padToHeightWidth pixelsH pixelsW
             --padColor hexcolor

⏺ Bash(SRC="/Users/alex/.claude/image-cache/2640f589-9b9e-41d5-b1f0-3f4ec921f0c6
      /5.png"
      OUT="/private/tmp/claude-501/-Users-alex-code-toshiba-t1200xe-keyboard/264
      0f589…)
  ⎿  /Users/alex/.claude/image-cache/2640f589-9b9e-41d5-b1f0-3f4ec921f0c6/5
     .png
       /private/tmp/claude-501/-Users-alex-code-toshiba-t1200xe-keyboard/26
     … +12 lines (ctrl+o to expand)

  Read 2 files (ctrl+o to expand)

⏺ Yes — I can see both flags clearly now that I've zoomed in, and I read the
  tiny silkscreened reference numbers next to each pad:

  - Blue tape #1 sits exactly on pad 120 (matches F9)
  - Blue tape #2 sits exactly on pad 118 (matches F7)
  - In between them, pad 119 is visible, unmarked — that's almost certainly F8
  (row5, col1), sitting physically right between F7 and F9 in this row of pads
  - Pad 121 (F10) and pads 11/12/10 (part of another key group) are also visible
  in these crops

  This is actually a very useful finding, and it changes where I'd point you to
  look. F8 sits physically between F7 and F9 on this edge, yet you've never seen
  F7↔F8 crosstalk — only F7↔F9 (a row5/row6 short) and separately F4↔F3 (a
  same-row, column short elsewhere). If the fault were simply two
  physically-neighboring pads touching or bridging right here at the keycap
  position, F8's pad — sitting directly between 118 and 120 — would be the first
  thing to short to one or both of its neighbors. It isn't affected.

  That tells us the short is not at this edge, at the keycap footprints 
  themselves. It has to be somewhere else on the board — wherever the copper
  traces for the row5 and row6 nets (which each run all the way from the
  connector, fanning out to reach all 11 columns) happen to pass close to one
  another. That crossing point could be anywhere: near the FFC connector, near a
  via, wherever the PCB designer routed those two traces in parallel for some
  stretch. It doesn't have to be anywhere near keys 118/119/120 visually.

  Given I can now read this board's silkscreen at this zoom level, here's how
  I'd narrow it down further:

  1. Probe directly at pads 118 and 120 with your multimeter (diode-test mode,
  board unpowered) — this is a cleaner, more localized test than probing at the
  Pico/FFC end, since it rules out the ribbon cable itself as a variable.
  2. If you can tell me (or show me) which FFC conductor carries row5 (GP15) and
  which carries row6 (GP22) — e.g. a photo of your wiring notes or the
  Pico-side connections — I can try to help visually trace those two specific
  copper traces across the board from crops like these, looking for where they
  run parallel/adjacent.
  3. Failing that, a systematic sweep: pick several other keys on row5 (col2
  onward — whatever's left of col0/col1 in that row) and row6, and
  multimeter-probe row5's pad against row6's pad at each, working across the
  board, until you find a spot where the reading changes from open to a
  short/leak.

  Want to send a photo of the component (top) side, or of your Pico wiring, so I
  can try to trace the actual row5/row6 net path rather than guessing?

✻ Baked for 2m 19s

※ recap: We're diagnosing hardware ghost-key crosstalk on your Toshiba T1200XE keyboard PCB. I just confirmed your blue tape correctly marks pads 118 (F7) and 120 (F9); next step is probing continuity between those two pads directly with your multimeter.

❯ [Image #6]                                                                    
                                                                                
  [Image #7]                                                                    
  ⎿  [Image #6]
[Image #7]

  Read 1 file (ctrl+o to expand)

⏺ This is the missing piece — and it lines up almost perfectly.
  Cross-referencing Table B-14 against the row/col pin order in code.py:17-26,
  assuming the wiring was done straight down the connector (KBRT0→row0,
  KBRT1→row1, … KBRT7→row7, skipping the GND at pin 18 — which would also
  explain why row_pins has that odd-looking, non-sequential GPIO order:
  GP11,GP12,GP13,GP14,GP20,GP15,GP22,GP21 is exactly what you'd get by wiring
  pins 14,15,16,17,19,20,21,22 in physical order to whatever breadboard pin was
  next):

  ┌─────────────┬────────┬───────────────┐
  │     Row     │ Signal │ Connector pin │
  ├─────────────┼────────┼───────────────┤
  │ row2 (F3)   │ KBRT2  │ 16            │
  ├─────────────┼────────┼───────────────┤
  │ row3 (Next) │ KBRT3  │ 17            │
  ├─────────────┼────────┼───────────────┤
  │ row4 (F5)   │ KBRT4  │ 19            │
  ├─────────────┼────────┼───────────────┤
  │ row5 (F7)   │ KBRT5  │ 20            │
  ├─────────────┼────────┼───────────────┤
  │ row6 (F9)   │ KBRT6  │ 21            │
  ├─────────────┼────────┼───────────────┤
  │ row7 (END)  │ KBRT7  │ 22            │
  └─────────────┴────────┴───────────────┘

  And for columns: col0 = KBOT00 = pin 1, col1 = KBOT01 = pin 2.

  Now check every ghost pair you've found against this table:

  - F3→Next: pins 16↔17 — adjacent
  - F5→F7: pins 19↔20 — adjacent
  - F7→F9: pins 20↔21 — adjacent
  - F9→END: pins 21↔22 — adjacent
  - F4→F3: pins 2↔1 — adjacent
  - F12→F11: pins 2↔1 — adjacent (same pin pair as F4→F3)
  - Next→F5: pins 17↔19 — one pin gap (pin 18 = GND sits between them)

  Six of seven ghost pairs land on physically consecutive connector pins. The
  seventh is off by exactly one pin — which happens to be the GND pin, so it's
  still the same tight cluster on the connector, just with the ground contact in
  between. That's about as clean a signature as you're going to get: every 
  single ghosting incident you've found corresponds to physically adjacent (or 
  near-adjacent) pins on this 22-pin keyboard connector — not to anything
  intrinsic to the PCB matrix, the keyswitches, or the diodes. That also
  retroactively explains why F8 (physically between F7 and F9 on the PCB, per
  the tape photos) was never affected — its pad location on the board is
  irrelevant, because the fault isn't there. It's at the connector, where F7's
  and F9's row lines (pins 20/21) happen to sit next to each other.

  This reframes the whole investigation: stop looking at the PCB
  matrix/keyswitch area entirely, and focus on the connector itself — most
  likely pins 1-2, and the contiguous run 16 through 22. Concretely:

  1. Find this 22-pin connector (the Sumitomo FFC you photographed earlier is
  almost certainly it, or its mate on the system side).
  2. Inspect pins 1-2 and 16-22 under magnification for bent/misaligned
  contacts, corrosion, oxidation, or debris bridging neighbors.
  3. If it's a ZIF-style connector, check the ribbon is fully and evenly seated
  and the latch/flap is fully closed — a ribbon inserted slightly crooked is a
  classic cause of exactly this "neighboring pin" crosstalk pattern, and is a
  much easier fix than a PCB repair.
  4. Clean with isopropyl alcohol and a soft brush/cotton swab, focusing on
  those two zones.
  5. With the multimeter, now that you have exact pin numbers, probe directly
  pin20↔pin21 and pin1↔pin2 at the connector itself (both at rest and under
  gentle flex of the ribbon) — this is a much more targeted test than anything
  we could do before.
  6. Re-run ghost_key_test.py with ONLY_TEST = ['F7'] after any
  cleaning/reseating to check for improvement.

✻ Brewed for 2m 25s

❯ Tell me more about With the multimeter, now that you have exact pin numbers,  
  probe directly pin20↔pin21 and pin1↔pin2 at the connector itself (both at     
  rest and under                                                                
    gentle flex of the ribbon) — this is a much more targeted test than         
  anything we could do before.                                                  
                                                                                
  Are we looking for short? Which polcarity?                                    

⏺ Good question to nail down before you start probing — here's the precise
  procedure.

  Meter mode: diode-test mode, not just the beep/continuity mode.
  Continuity mode only tells you "below some threshold resistance, beep" —
  usually a few tens of ohms — and hides the actual number. Diode-test mode
  pushes a small current through the probes and shows you a voltage, which lets
  you distinguish three very different situations instead of just pass/fail:

  - ~0.00–0.05V → a dead short (near-zero resistance) — a proper bridge, e.g.
  tin/solder or debris directly connecting the two pins.
  - A stable diode-like drop, roughly 0.3–0.7V in one direction, OL (open) the 
  other way → a rectifying junction — this is the "corrosion acting like an
  accidental diode" scenario I mentioned earlier. Note it doesn't have to hit
  the textbook silicon 0.6V exactly; corrosion junctions are messier. Any non-OL
  reading in only one direction counts.
  - OL both directions but the reading flickers/jumps toward a value while 
  you're flexing → a marginal, contact-dependent leak — not a hard short at all,
  just barely-touching material that makes and breaks contact with movement.
  This matches the timing behavior you've already seen (10-70ms lag,
  inconsistent release order), so this is honestly the outcome I'd bet on.

  Before you touch anything: unplug the Pico from USB. With it powered and
  running, the GPIO pins are actively driven/pulled by the microcontroller, and
  the meter's tiny test current will be fighting that — you'll get confusing,
  unstable readings that don't reflect the connector itself. You want both lines
  fully floating.

  Polarity: test both directions, as two separate readings.
  1. Red probe on pin 20 (row5/F7), black probe on pin 21 (row6/F9). Note the
  reading.
  2. Swap: red on 21, black on 20. Note the reading.

  Do the same for pins 1 and 2. The reason to check both: since we found the
  F4→F3 and F12→F11 ghosts only ever go one direction (never the reverse), if
  there's a real asymmetric junction at pins 1/2, you'd expect the diode-mode
  reading to differ noticeably between the two polarities — confirming that
  asymmetry electrically rather than just behaviorally.

  What "normal/healthy" looks like, so you know what you're comparing against:
  at rest, with no keys pressed, there is no legitimate electrical path between
  two row lines (or two column lines) at all — every real path in this matrix
  goes row→diode→column through an actual keypress. So on a healthy pair, you
  should get OL in both directions, full stop. Any reading at all — short,
  diode-like, or a flickery near-open — is abnormal and is your evidence.

  The flex test: hold both probes steady on the two pins (resting them so they
  don't slip is easier than trying to hold pressure the whole time — alligator
  clips or a helping hand are useful here), watch the display, and with your
  other hand gently bow/wiggle the ribbon cable right where it enters the
  connector, and separately try pressing on the connector body itself. You're
  watching for the reading to jump from OL to something during the flex — that's
  the moment you've caught it in the act. If your meter has a MIN/MAX-hold or a
  peak-capture mode, use it, since a brief flex-induced blip can be easy to
  miss on a normal 2-3-reading-per-second display.

  One practical caution: if this is a fine-pitch FFC connector, don't jam meter
  probes into the housing — you risk bending or spreading the tiny contacts.
  Probe at the PCB-side solder pads for those pins instead (same net, easier and
  safer to reach), and use needle-tip probes if you have them so you don't
  accidentally bridge two adjacent pads yourself with a fat probe tip and
  produce a false short.

✻ Brewed for 1m 4s

※ recap: Debugging ghost key presses on the Toshiba keyboard; you traced the fault to connector pins 20/21 and 1/2. Next: multimeter-probe those pins in diode mode while flexing the ribbon to catch the intermittent short.

❯ on all 4 measurements my multimeter shows "1." that means there is infinite   
  resistance and no contact at all                                              

⏺ That "1." (OL / open) result is actually exactly what we'd expect, not a dead
  end — it confirms the fault isn't a permanent bridge, which matches everything
  else you've found: the ghosting is intermittent (F7→F9 fires roughly 2 in 5
  presses, not every time), with variable lag and inconsistent release order. A
  static, at-rest reading was never going to catch that — you already proved the
  same thing weeks... earlier with the GP13/GP14 check on row2/row3, which was
  also clean at rest despite that pair genuinely ghosting in use.

  So the real test is reproducing the actual triggering condition while watching
  the meter. Two ways to do that, worth trying both:

  1. Flex the connector/ribbon itself, as originally suggested — clip the probes
  onto pins 20 and 21 (use alligator leads so your hands are free, rather than
  trying to hold probes steady by hand), then gently bow the ribbon where it
  meets the connector, wiggle it side to side, and press on the connector
  housing itself. Watch for the display to jump off "1." even briefly.

  2. Press the actual F7 key while probing. This is arguably the more faithful
  test, since we know for a fact that a real F7 keypress is what triggers the
  ghost — not an abstract cable wiggle. With the Pico still unplugged (so the
  rows aren't being driven, which is fine — you're testing for a physical
  bridge, not a logic-level event) and the meter clipped to pins 20/21, have
  someone press F7 repeatedly (or do it one-handed if you're alone) and watch
  for a blip. If your meter has a MIN/MAX-hold or peak-capture function, turn it
  on first — a keypress-induced blip may only last a few milliseconds, easy to
  miss on a normal refresh-rate display, and hold mode will catch it and freeze
  it for you to read.

  If neither flexing the cable nor pressing F7 ever produces a blip on the
  connector pins, that would actually point back away from the connector and
  toward something closer to the keyswitch/PCB trace level after all — so this
  test is genuinely decisive either way, not just confirmatory.

✻ Baked for 47s

❯ in diode does current flow from cathode to anode? Meaning if I apply + to     
  cathod and - to anode will current flow?                                      

⏺ No — it's the opposite. Current flows anode → cathode through a diode when
  forward biased (anode more positive than cathode). If you put + on the cathode
  and − on the anode, that's reverse bias, and a healthy diode blocks it —
  you'd read OL ("1.") on the meter, not a voltage drop.

  So on your multimeter in diode-test mode: the red probe is the internal +
  source, black is −.
  - Red on anode, black on cathode → forward bias → meter shows a voltage drop
  (typically ~0.4–0.7V for silicon, sometimes lower for germanium/Schottky) —
  this confirms the diode is good and oriented that way.
  - Red on cathode, black on anode → reverse bias → meter shows OL — also
  expected/good, confirms the diode isn't leaking backward.

  One thing worth knowing for this specific keyboard if you ever want to test
  one of the actual per-key diodes (not the row-to-row connector test we've been
  doing): the README notes this matrix uses columns_to_anodes=False, meaning
  it's wired opposite to the usual convention — the row lines are the anodes, 
  and the column lines are the cathodes. So to check a healthy individual key's
  diode, you'd hold that key physically pressed (to close the switch and
  complete the path) and put red on that key's row pin, black on its column pin,
  and expect a forward drop; swapped, you should get OL.

✻ Worked for 21s

※ recap: Debugging ghost keys on your Toshiba T1200XE keyboard build. We traced F7/F9 crosstalk to connector pins 20/21; next step is watching the multimeter for a blip while flexing the ribbon or pressing F7.

❯ OK, I've disconnected the keyboard from pico and ran diagnostics for F7 only. 
  I did not get any ghosts, so it is somewhere in the flat keyboard cable and   
  keyboard PCB itself. Now, when I used multimeter to check pins 21 and 1 for   
  continuity when I press F7 - it did not show any short, so the short must be  
  happening so quickly that multimeter cannot detect it, but Pico can. Ccan you 
  help me setup measurement using an oscilloscope in hope to catch that cross   
  talking spike? I really want to get it measurable so I can confirm that it's  
  gone when I fix it.                                                           

⏺ Good instinct — a DMM samples a few times a second, so anything shorter than
  ~200-300ms is invisible to it. A capacitive-coupling or marginal-contact
  glitch that only needs to persist a couple of milliseconds to fool the
  RP2040's scanner would sail right past a handheld meter. A scope is the right
  tool now.

  What to probe (this matters more than the scope settings):
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

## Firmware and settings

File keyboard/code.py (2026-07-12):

import board

from kmk.kmk_keyboard import KMKKeyboard
from kmk.keys import KC
from kmk.modules.layers import Layers
from kmk.scanners import DiodeOrientation
from kmk.utils import Debug

# from kmk.scanners.keypad import MatrixScanner
from ghost_filter import GhostFilterMatrixScanner

Debug(__name__).enabled = True

# Copy this code to CIRCUITPY\code.py

keyboard = KMKKeyboard()
keyboard.modules.append(Layers())

keyboard.row_pins = (
    board.GP11, board.GP12, board.GP13, board.GP14,
    board.GP20, board.GP15, board.GP22, board.GP21,
)

keyboard.col_pins = (
    board.GP0, board.GP1, board.GP2, board.GP4,
    board.GP3, board.GP6, board.GP5, board.GP7,
    board.GP8, board.GP9, board.GP10,
)

# Toshiba matrix is active-high: rows HIGH, columns PULL_DOWN → ROW2COL.
keyboard.diode_orientation = DiodeOrientation.ROW2COL

# keypad.KeyMatrix default interval=0.02s (20ms/scan), threshold=1 = no debounce.
# debounce time = interval * threshold, so keep interval short and threshold moderate.
# interval=0.002 + threshold=15 → ~30ms debounce. Raise threshold if Enter still bounces.
keyboard.matrix = GhostFilterMatrixScanner(
# keyboard.matrix = MatrixScanner(
    column_pins=keyboard.col_pins,
    row_pins=keyboard.row_pins,
    columns_to_anodes=keyboard.diode_orientation,
    interval=0.002,
    debounce_threshold=15,
)

NO  = KC.NO
___ = KC.TRNS

keyboard.keymap = [
    # -----------------------------------------------------------------------
    # Layer 0 — base
    # -----------------------------------------------------------------------
    [
        # Col:  0        1        2        3        4        5        6        7        8        9        10
        KC.F1,  KC.F2,  KC.ESC,  KC.N2,  KC.N4,  KC.N6,  KC.N8,  KC.N0,   KC.EQL,  KC.BSPC, KC.PAUS,  # row 0
        KC.F11, KC.F12, KC.N1,   KC.N3,  KC.N5,  KC.N7,  KC.N9,  KC.MINS, KC.UP,   KC.DOWN, KC.MO(1), # row 1: Fn → MO(1)
        KC.F3,  KC.F4,  KC.TAB,  KC.W,   KC.R,   KC.Y,   KC.I,   KC.P,    KC.LBRC, KC.HOME, NO,       # row 2
        KC.PGDN,KC.PGUP,KC.Q,    KC.E,   KC.T,   KC.U,   KC.O,   KC.LEFT, KC.RBRC, KC.ENT,  NO,       # row 3
        KC.F5,  KC.F6,  KC.A,    KC.S,   KC.F,   KC.H,   KC.J,   KC.L,    KC.RIGHT,KC.GRV,  NO,       # row 4
        KC.F7,  KC.F8,  KC.LCTL, KC.D,   KC.G,   KC.B,   KC.K,   KC.SCLN, KC.QUOT, KC.RSFT, NO,       # row 5
        KC.F9,  KC.F10, KC.LSFT, KC.Z,   KC.V,   KC.N,   KC.COMM,KC.DOT,  KC.SLSH, KC.PSCR, NO,       # row 6
        KC.END, KC.LALT,KC.BSLS, KC.X,   KC.C,   KC.SPC, KC.M,   KC.DEL,  KC.CAPS, KC.INS,  NO,       # row 7
    ],
    # -----------------------------------------------------------------------
    # Layer 1 — Fn overlay
    #   Activated momentarily by holding Fn (MO(1)).
    #   Toggled permanently by Fn+F11 (TG(1)) = NumLock behaviour.
    #   Keys marked NO have Toshiba-specific functions (Slow/Fast CPU speed,
    #   IntDisp/ExtDisp display routing, Font size, Overlay mode) with no
    #   standard HID equivalent.
    #   Digits/operators use plain HID keyboard-page keys (KC.N4, KC.MINS, ...)
    #   rather than KC.KP_* (HID keypad-page). Keypad-page codes only resolve
    #   to digits when the host's own Num Lock is on, and this firmware can't
    #   read or drive that LED state — on Linux/RPi they were resolving as
    #   navigation keys (arrows/Home/etc.) instead of digits. Plain keys always
    #   type the digit/symbol regardless of host Num Lock state.
    # -----------------------------------------------------------------------
    [
    # Col:
    #   0         1               2        3    4    5      6      7        8        9    10
        ___,      ___,            NO,      ___, ___, ___,   KC.N8, KC.ASTR, ___,     ___, ___, # row 0: 8→8, 0→*; Esc→PopUp (no HID)
        KC.TG(2), KC.SCROLL_LOCK, ___,     ___, ___, KC.N7, KC.N9, ___,     ___,     ___, ___, # row 1: F11→TG(2) NumLock, F12→ScrLk, 7→7, 9→9
        ___,      ___,            ___,     ___, ___, ___,   KC.N5, KC.MINS, ___,     NO,  NO,  # row 2: i→5, p→-; Home→IntDisp (no HID)
        NO,       NO,             ___,     ___, ___, KC.N4, KC.N6, ___,     ___,     ___, NO,  # row 3: PgDn→Slow, PgUp→Fast (no HID); u→4, o→6
        ___,      ___,            ___,     ___, ___, ___,   KC.N1, KC.N3,   NO,      ___, NO,  # row 4: j→1, l→3; Right→Font (no HID)
        ___,      ___,            KC.LGUI, ___, ___, ___,   KC.N2, KC.PLUS, ___,     ___, NO,  # row 5: Ctrl→Cmd; k→2, ;→+
        ___,      NO,             ___,     ___, ___, ___,   ___,   KC.DOT,  KC.SLSH, ___, NO,  # row 6: F10→Overlay (no HID); .→., /→/
        NO,       ___,            ___,     ___, ___, ___,   KC.N0, ___,     ___,     ___, NO,  # row 7: End→ExtDisp (no HID); m→0
    ],
    # -----------------------------------------------------------------------
    # Layer 2 — NumLock (permanent numpad)
    #   Toggled on/off by Fn+F11 (TG(2) in layer 1).
    #   F11 alone also toggles it off (TG(2) here).
    #   Only numpad keys — no other Fn shortcuts — so normal keys like
    #   PgDn/PgUp/Home remain reachable when NumLock is on.
    #   Same plain-key rationale as layer 1 above.
    # -----------------------------------------------------------------------
    [
    # Col:
    #   0         1    2    3    4    5      6      7        8        9    10
        ___,      ___, ___, ___, ___, ___,   KC.N8, KC.ASTR, ___,     ___, ___, # row 0: 8→8, 0→*
        KC.TG(2), ___, ___, ___, ___, KC.N7, KC.N9, ___,     ___,     ___, ___, # row 1: F11→unlock NumLock, 7→7, 9→9
        ___,      ___, ___, ___, ___, ___,   KC.N5, KC.MINS, ___,     ___, NO,  # row 2: i→5, p→-
        ___,      ___, ___, ___, ___, KC.N4, KC.N6, ___,     ___,     ___, NO,  # row 3: u→4, o→6
        ___,      ___, ___, ___, ___, ___,   KC.N1, KC.N3,   ___,     ___, NO,  # row 4: j→1, l→3
        ___,      ___, ___, ___, ___, ___,   KC.N2, KC.PLUS, ___,     ___, NO,  # row 5: k→2, ;→+
        ___,      ___, ___, ___, ___, ___,   ___,   KC.DOT,  KC.SLSH, ___, NO,  # row 6: .→., /→/
        ___,      ___, ___, ___, ___, ___,   KC.N0, ___,     ___,     ___, NO,  # row 7: m→0
    ],
]

if __name__ == '__main__':
    keyboard.go()

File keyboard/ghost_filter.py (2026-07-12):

"""
Suppresses known ghost key-events caused by the hardware crosstalk on this
keyboard's connector (see README / diagnostics/ghost_key_test.py).

Wraps MatrixScanner and drops a ghost key's press+release if it appears
within GHOST_SUPPRESS_WINDOW seconds of its known trigger key while that
trigger is still held. Operates on raw key_number matrix events, below
KMK's key-processing, so it applies on every layer.

Trade-off: if a suppressed key is ever legitimately pressed within the
window while its trigger is held, that legitimate press is dropped too.
Only safe because none of these pairs are normally used in succession.
"""

import time

from kmk.scanners.keypad import MatrixScanner

GHOST_SUPPRESS_WINDOW = 0.2  # seconds; observed lag was 10-72ms

# trigger key_number -> set of ghost key_numbers to swallow if seen shortly
# after the trigger while it's still held. key_number = row * 11 + col.
GHOST_MAP = {
    22: {33},  # F3 -> PgDn/Next
    33: {44},  # PgDn/Next -> F5
    44: {55},  # F5 -> F7
    55: {66},  # F7 -> F9
    66: {77},  # F9 -> End
    56: {67},  # F8 -> F10
    12: {11},  # F12 -> F11
    23: {22},  # F4 -> F3
}


class GhostFilterMatrixScanner(MatrixScanner):
    def __init__(self, *args, **kwargs):
        super().__init__(*args, **kwargs)
        self._held_triggers = {}  # key_number -> press timestamp
        self._suppressing = set()  # ghost key_numbers currently being eaten

    def scan_for_changes(self):
        while True:
            ev = super().scan_for_changes()
            if ev is None:
                return None

            kn = ev.key_number

            if kn in self._suppressing:
                if not ev.pressed:
                    self._suppressing.discard(kn)
                continue

            if ev.pressed:
                now = time.monotonic()
                ghosted = False
                for trig, ghosts in GHOST_MAP.items():
                    if (
                        kn in ghosts
                        and trig in self._held_triggers
                        and now - self._held_triggers[trig] <= GHOST_SUPPRESS_WINDOW
                    ):
                        ghosted = True
                        break
                if ghosted:
                    self._suppressing.add(kn)
                    continue
                if kn in GHOST_MAP:
                    self._held_triggers[kn] = now
            else:
                self._held_triggers.pop(kn, None)

            return ev

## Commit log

2026-07-12 Add ghost-key diagnostics, filter, and serial console docs
    Investigated intermittent ghosting on the F-key strip (traced to
    connector-pin crosstalk, fixed with IPA cleaning) and a PrtSc no-event
    issue. Adds standalone diagnostic tools to test the matrix independent
    of KMK, a scanner-level ghost-suppression filter as a firmware
    mitigation, README instructions for opening the serial console, and a
    write-up of the whole investigation.
    [code.py, ghost_filter.py, ghost_key_test.py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]
2026-07-12 Replace KP_* keypad codes with plain digit keys in Fn/NumLock overlays
    Keypad HID-page codes only resolve to digits when the host's own Num
    Lock is enabled; this firmware can't read or drive that LED state, so
    on Linux/RPi u/i/o etc. were resolving as navigation keys instead of
    4/5/6. Plain keyboard-page keys always type the digit/symbol.
    [code.py]
2026-07-12 Document PAM8406 audio setup, disable Pico's phantom USB-Audio interface
    AUDIO.md walks through diagnosing the RPi analog jack routing (HDMI vs
    bcm2835 card confusion) and pins the fix persistently. boot.py disables
    CircuitPython's default USB MIDI interface, which otherwise enumerates
    as a spurious ALSA sound card on the host.
2026-07-24 add keycap puller
    [keycap-puller-v3.f3d, keycap-puller-v3.stl]
2026-07-24 add docs etc
    [keyboard-matrix-pin-out.xlsx]
2026-07-25 add display docs, rename to pitoshi
    [bom.xlsx]
2026-07-26 add display frame Fusion model
    [toshiba-screen-frame.f3d]
2026-07-31 update bom
    [bom.xlsx]
